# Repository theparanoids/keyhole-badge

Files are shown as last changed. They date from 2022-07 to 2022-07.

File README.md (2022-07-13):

# Paranoids DEFCON Badge
> PCB design and firmware for a badge given out at DEFCON 2022

## Table of Contents

- [Background](#background)
- [Install](#install)
- [Usage](#usage)
- [Contribute](#contribute)
- [License](#license)

## Background

The Paranoids have designed a sound-reactive LED electronic conference badge for DEFCON 2022. This repository contains the PCB design files for the badge and the source code to the firmware that runs on the microcontroller.

This badge is designed around a Nordic [nRF52833](https://www.nordicsemi.com/Products/nRF52833) SoC embedded in a Laird [BL653](https://www.lairdconnect.com/wireless-modules/bluetooth-modules/bluetooth-5-modules/bl653-series-bluetooth-51-802154-nfc-module) module. The badge features wireless connectivity (Bluetooth Low Energy in this firmware implementation), a NFC coil, a microphone, buttons, and LEDs.

The firmware is built using the [nRF Connect SDK](https://www.nordicsemi.com/Products/Development-software/nRF-Connect-SDK) and [Zephyr RTOS](https://zephyrproject.org/). It advertises BLE beacons and listens for beacons coming from neighboring badges, lighting up the LEDs according to the number of badges detected. It also blinks the LEDs either in response to sound or in other patterns, which are unlocked by inputting secret codes using the buttons.

## Install

In order to edit the PCB design files, you will need to install [Kicad](https://www.kicad.org/) version 6 or above. The badge design is located in the `eda/` subdirectory. A pogo pin jig used during manufacturing is located in the `jig/` subdirectory. Opening the `.kicad_pro` project file should automatically load both the schematic and PCB design.

If you only want to view the schematic or the final board layout, PDFs of the final version are located in [final-artefacts](final-artefacts).

In order to compile the firmware, you will need to install the [Nordic nRF Connect SDK](https://www.nordicsemi.com/Products/Development-software/nrf-connect-sdk) v1.9.0. This can be installed according to the official instructions. If you are using nRF Connect for Desktop and the Toolchain Manager, select "Open Terminal" from the arrow dropdown after installing the SDK. From this terminal, the firmware can be built using the following command:

```bash
cd fw/
west build
```

The output will be located in `fw/build/zephyr/zephyr.elf`.

There are miscellaneous scripts written in Python that were used during testing and development. These require Python3, pySerial, NumPy, and scikit-image. These can be installed via pip using the following commands:

```bash
# Create a new Python virtual environment
python3 -m venv venv
# Activate the virtual environment
source venv/bin/activate
# Install libraries
pip install pyserial numpy scikit-image
```

LED positions were computed using [SolveSpace](https://solvespace.com/). This is saved in the [notes.slvs](eda/notes.slvs) file.

## Usage

The Paranoids badge does not contain any kind of bootloader or firmware update functionality, so installing new firmware requires connecting to SWD (Serial Wire Debug) test pads on the back of the badge. This can be done either with a temporary jig or by soldering wires or pin headers. The test points are labeled on the [backside fabrication drawing](final-artefacts/badge/pdf/badge_eda-B_Fab.pdf). Connections that are required are as follows:

* `TP3 / +V` -- Microcontroller supply voltage. This may be labeled as "VCC" or "Vtarget" or similar. Corresponds to pin 1 of the ARM 10-pin connector. **Caution**: This pin is intended to be used as a voltage reference and not as a means to power the badge. Although powering the badge from this test point does work, doing so will bypass the reverse polarity protection circuitry. There is also no protection against back-powering the battery, which can result in a dangerous condition. If power is supplied using this test point, ensure that connections are correct and that batteries are not installed. Nominal voltage 3 V.
* `TP9 / GND` -- Ground reference. Corresponds to pins 3/5/9 of the ARM 10-pin connector.
* `TP5 / SWDCLK` -- SWD clock pin. Corresponds to pin 4 of the ARM 10-pin connector.
* `TP6 / SWDIO` -- SWD data pin. Corresponds to pin 2 of the ARM 10-pin connector.
* `TP4 / ~RST` (optional) -- reset pin (active low). Corresponds to pin 10 of the ARM 10-pin connector. Not required in most cases as reset can be triggered over SWD.
* `TP7 / DBGTX` (optional) -- debug serial port, output from the board. In this firmware, this is configured with a 115200 baud 8n1 serial port for printing debug messages.
* `TP8 / DBGRX` (optional) -- debug serial port, input into the board. In this firmware, this is technically configured as part of the debug console, but input is never read.

All signals are referenced to the voltage on `TP3`.

Programming new firmware requires an external ARM SWD debug probe, such as a [Black Magic Probe](https://1bitsquared.com/products/black-magic-probe) or a [J-Link](https://www.segger.com/products/debug-probes/j-link/). It is also possible to [use a Raspberry Pi](https://learn.adafruit.com/programming-microcontrollers-using-openocd-on-raspberry-pi) or any other compatible debug adapter.

Example commands for programming using a Black Magic Probe:

```
$ arm-none-eabi-gdb build/zephyr/zephyr.elf
(gdb) target extended-remote /dev/cu.usbmodemXXXXXXXX
(gdb) monitor swdp_scan
(gdb) attach 1
(gdb) load
```

### Firmware debugging features

The badge connects the USB pins of the nRF52 chip to a USB micro-B connector on the bottom of the board. In this firmware, this is configured as a CDC-ACM serial port featuring a debug console (different from the one on the test points). Typing `help` will show a list of debug commands.

This USB debug console allows for capturing sound onto a connected computer. To capture sound, send the command `debug sound on`. The badge will then continuously output a stream of audio samples in signed 16-bit little endian format at 16 kHz with no framing. The [test_sound.py](fw/src/test_sound.py) script demonstrates capturing approximately 10 seconds of audio via this mechanism and writing it to a raw file which can be opened in tools such as [Audacity](https://www.audacityteam.org/).

If the flash memory of the nRF52 is blank, the firmware will start in factory test mode. Completion of factory testing is stored in flash memory, so none of the badges given out at DEFCON will start in test mode. As long as the Zephyr NVS data at the end of flash memory is not erased when programming new firmware, the badge will not enter test mode again. Test mode can be either re-entered after completion or forcefully bypassed without completing it by using the USB debug console. The factory test procedure goes through the following phases:

1. Both eyes should be red. The edge LEDs should have a pattern of three lit LEDs animating and moving around in a loop. The other LEDs on the edge should be off. One LED should be blue, the next should be green, and the final lit LED should be red. The primary purpose of this test phase is to ensure that there are no breaks in the LED chain. To proceed to the next phase, press button SW1.
2. Both eyes should be green. One LED on the edge, immediately below the eyes, should be white. All other LEDs on the edge should be off. To proceed to the next phase, press button SW2.
3. Both eyes should be blue. Two LEDs on the edge, immediately below the eyes, should be white. All other LEDs on the edge should be off. To proceed to the next phase, press button SW3.
4. Both eyes should be white. Three LEDs on the edge, immediately below the eyes, should be white. All other LEDs on the edge should be off. To proceed to the next phase, press button SW4.
5. Both eyes should be white. All LEDs on the edge should be white. At this point in the test procedure, the edge LEDs, all three primary colors of the eye LEDs, and all buttons will have been tested. This phase with all LEDs lit also serves as a brief test of maximum current draw in order to try to catch obvious issues with the 5 V SMPS. To proceed to the next phase (finishing and exiting test mode), play a 440 Hz tone. This tests the microphone.

## Contribute

Please refer to [the contributing.md file](Contributing.md) for information about how to get involved.

## Maintainers
- R: rou@yahooinc.com

## License
- This project is licensed under the terms of the [Apache 2.0](LICENSE-Apache-2.0) open source license. Please refer to [LICENSE](LICENSE) for the full terms.

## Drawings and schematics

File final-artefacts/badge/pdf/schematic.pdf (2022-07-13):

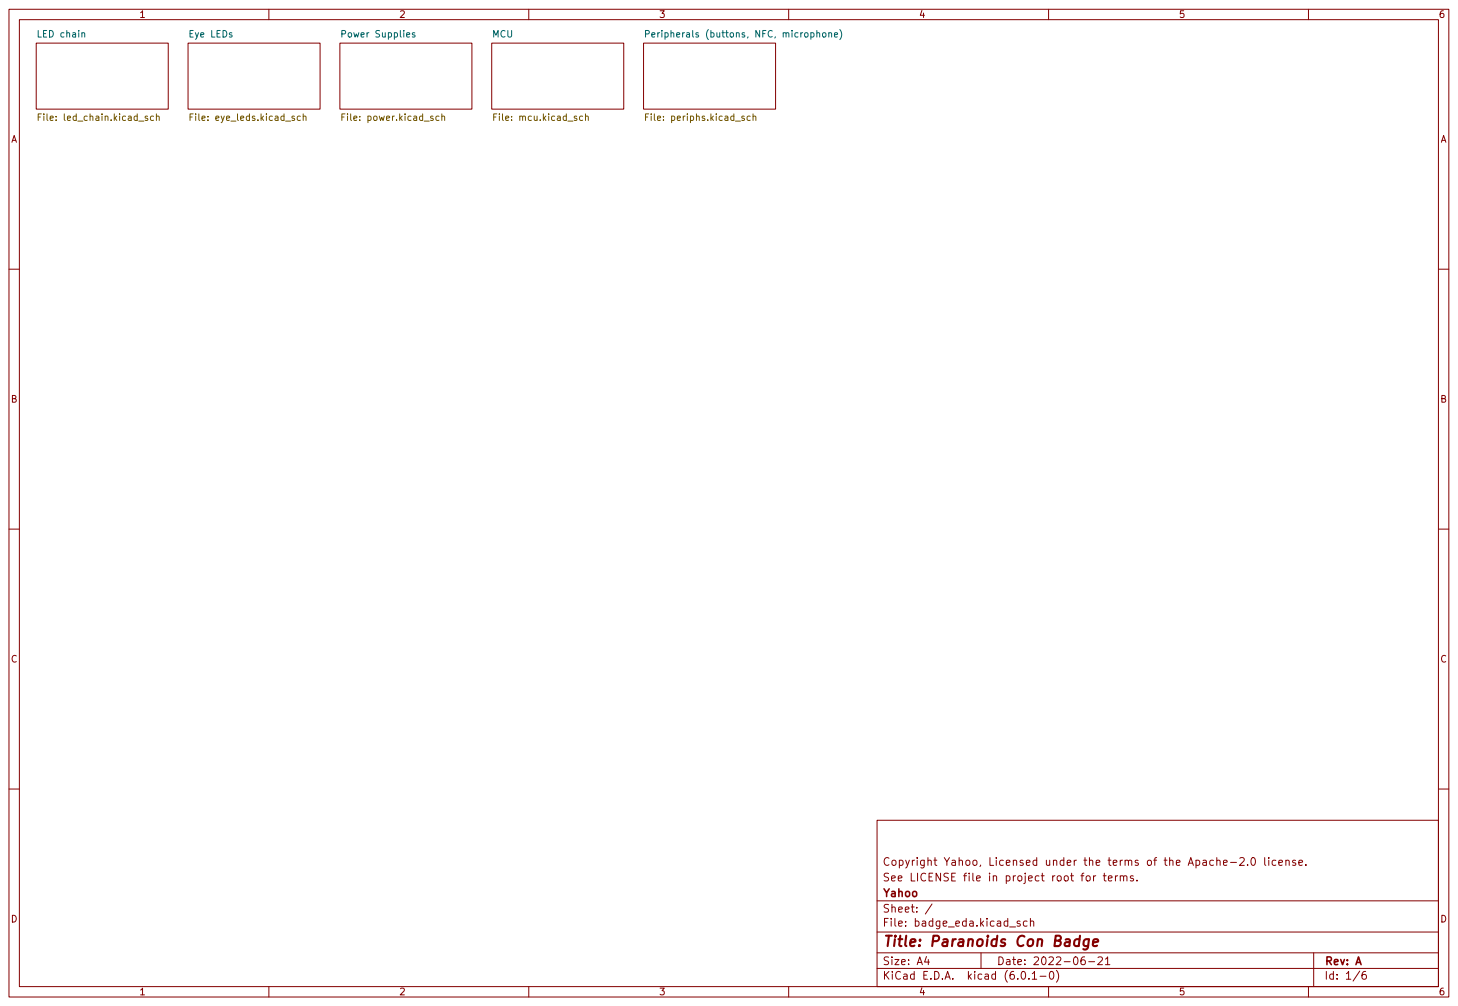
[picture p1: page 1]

Peripherals (buttons, NFC, microphone)

Copyright Yahoo, Licensed under the terms of the Apache-2.0 license.
File: badge_eda.kicad_sch Sheet: / Yahoo See LICENSE file in project root for terms.

Id: 1/6 Title: Paranoids Con Badge

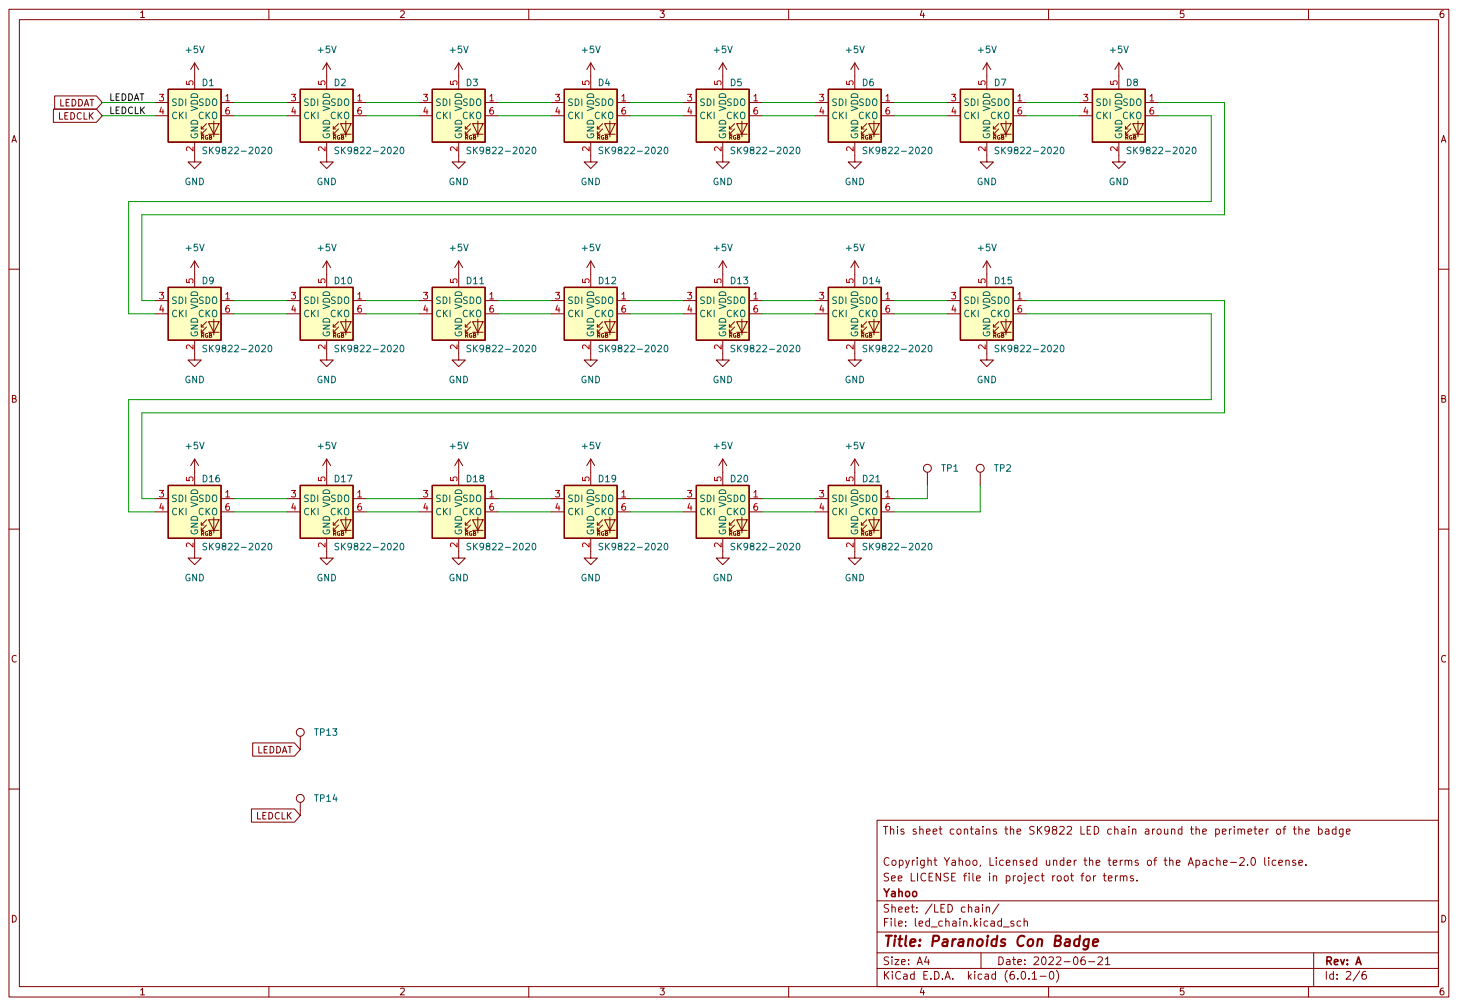
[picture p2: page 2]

This sheet contains the SK9822 LED chain around the perimeter of the badge

Copyright Yahoo, Licensed under the terms of the Apache-2.0 license.
File: led_chain.kicad_sch Sheet: /LED chain/ Yahoo See LICENSE file in project root for terms.

Id: 2/6 Title: Paranoids Con Badge

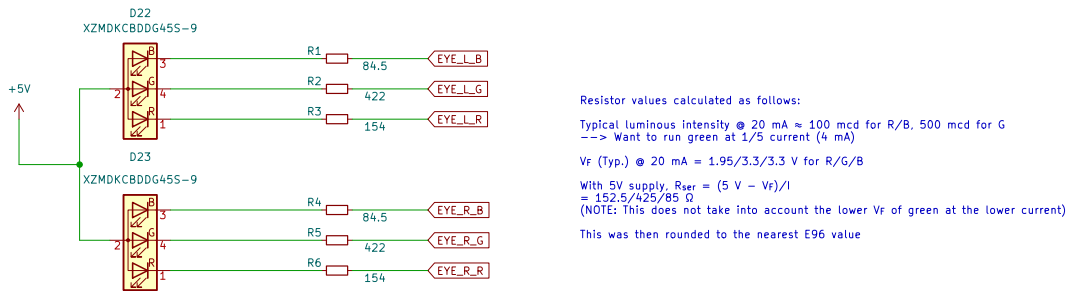
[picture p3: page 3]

Resistor values calculated as follows: þÿTypical luminous intensity @ 20 mA "H 100 mcd for R/B, 500 mcd for G

--> Want to run green at 1/5 current (4 mA)

With 5V supply, R_{ser} = (5 V - V_{F})/I
(NOTE: This does not take into account the lower V_{F} of green at the lower current) This was then rounded to the nearest E96 value

This sheet contains the RGB LEDs that light up behind the eyes

Copyright Yahoo, Licensed under the terms of the Apache-2.0 license.
Sheet: /Eye LEDs/ Yahoo See LICENSE file in project root for terms.

File: eye_leds.kicad_sch
Id: 3/6 Title: Paranoids Con Badge

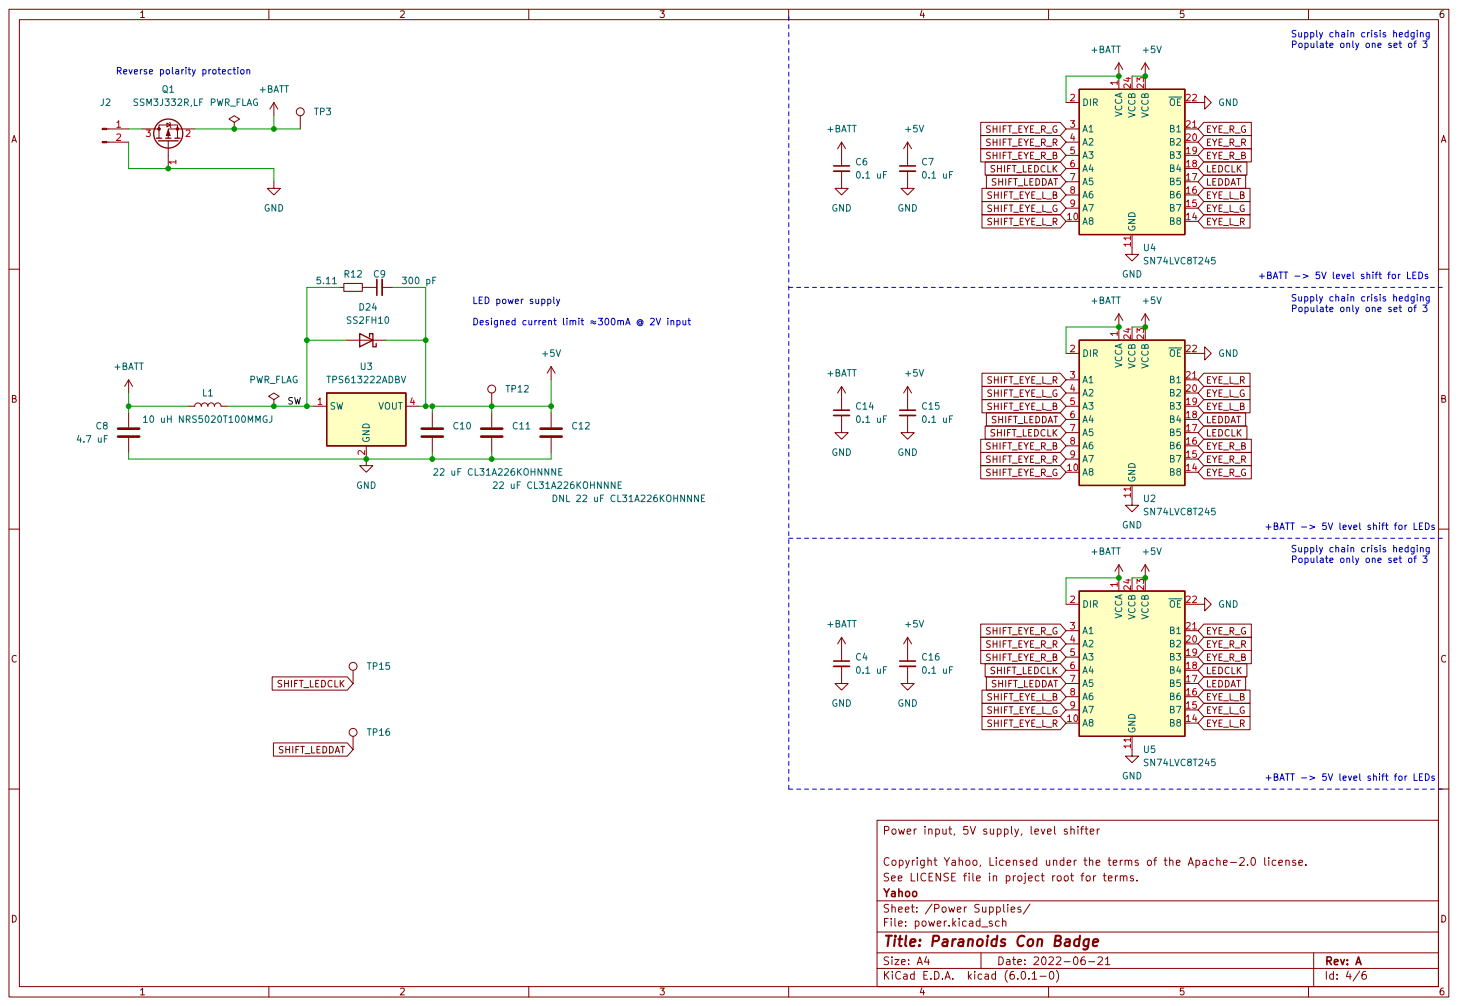
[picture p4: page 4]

Supply chain crisis hedging
Populate only one set of 3
Populate only one set of 3 +BATT -> 5V level shift for LEDs Supply chain crisis hedging

1 A8 10 GND 11 B8 14 B7 15 B6 16 B5 17 B4 18 B3 19 DIR 2 B2 20 B1 21 ~{OE}22 VCCB 23 VCCB 24 A1 3 A2 4 A3 5 A4 6 A5 7 A6 8 A7 9 U4SN74LVC8T245 +5V C12 DNL 22 uF CL31A226KOHNNNE

1 A8 10 GND 11 B8 14 B7 15 B6 16 B5 17 B4 18 B3 19 DIR 2 B2 20 B1 21 ~{OE}22 VCCB 23 VCCB 24 A1 3 A2 4 A3 5 A4 6 A5 7 A6 8 A7 9 U2SN74LVC8T245 GND

+BATT -> 5V level shift for LEDs +BATT -> 5V level shift for LEDs Supply chain crisis hedging

1 A8 10 GND 11 B8 14 B7 15 B6 16 B5 17 B4 18 B3 19 DIR 2 B2 20 B1 21 ~{OE}22 VCCB 23 VCCB 24 A1 3 A2 4 A3 5 A4 6 A5 7 A6 8 A7 9 U5SN74LVC8T245

Power input, 5V supply, level shifter

Copyright Yahoo, Licensed under the terms of the Apache-2.0 license.
Sheet: /Power Supplies/ Yahoo See LICENSE file in project root for terms.

File: power.kicad_sch
Id: 4/6 Title: Paranoids Con Badge

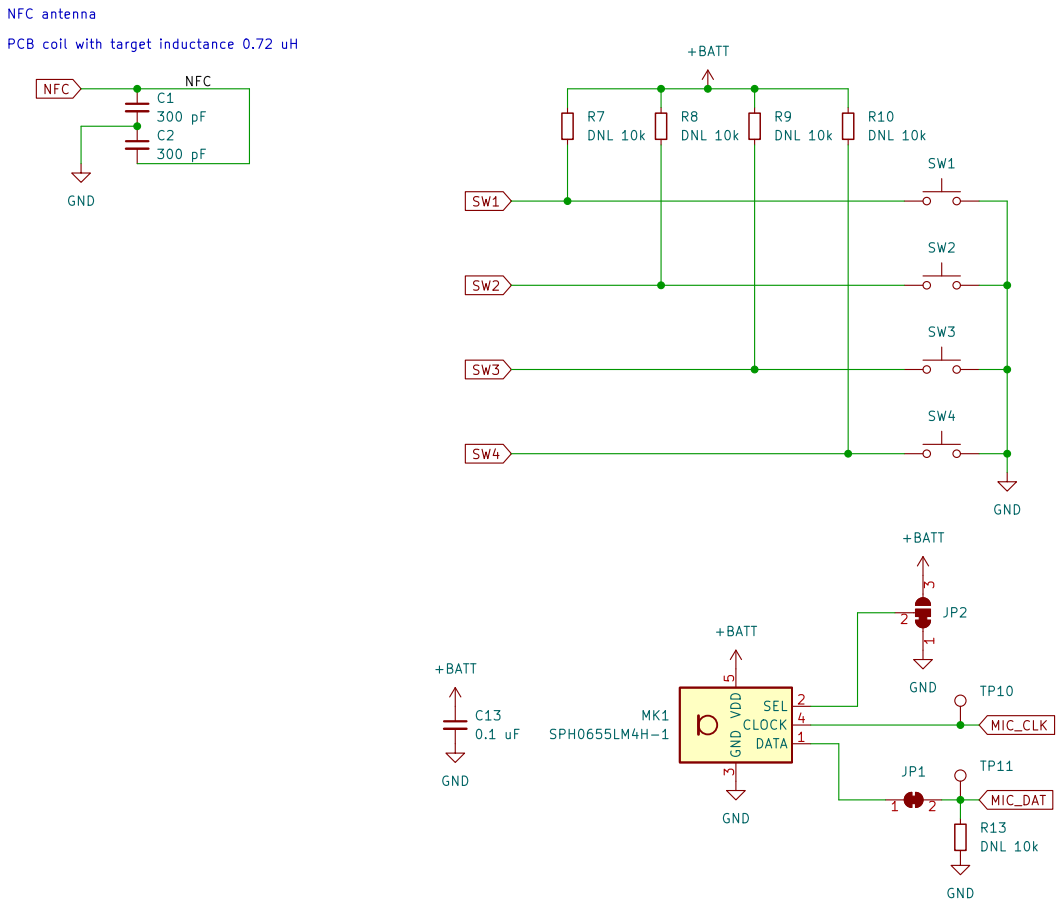
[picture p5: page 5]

NFC antenna PCB coil with target inductance 0.72 uH

Copyright Yahoo, Licensed under the terms of the Apache-2.0 license.
Sheet: /Peripherals (buttons, NFC, microphone)/ Yahoo See LICENSE file in project root for terms.

File: periphs.kicad_sch
Id: 5/6 Title: Paranoids Con Badge

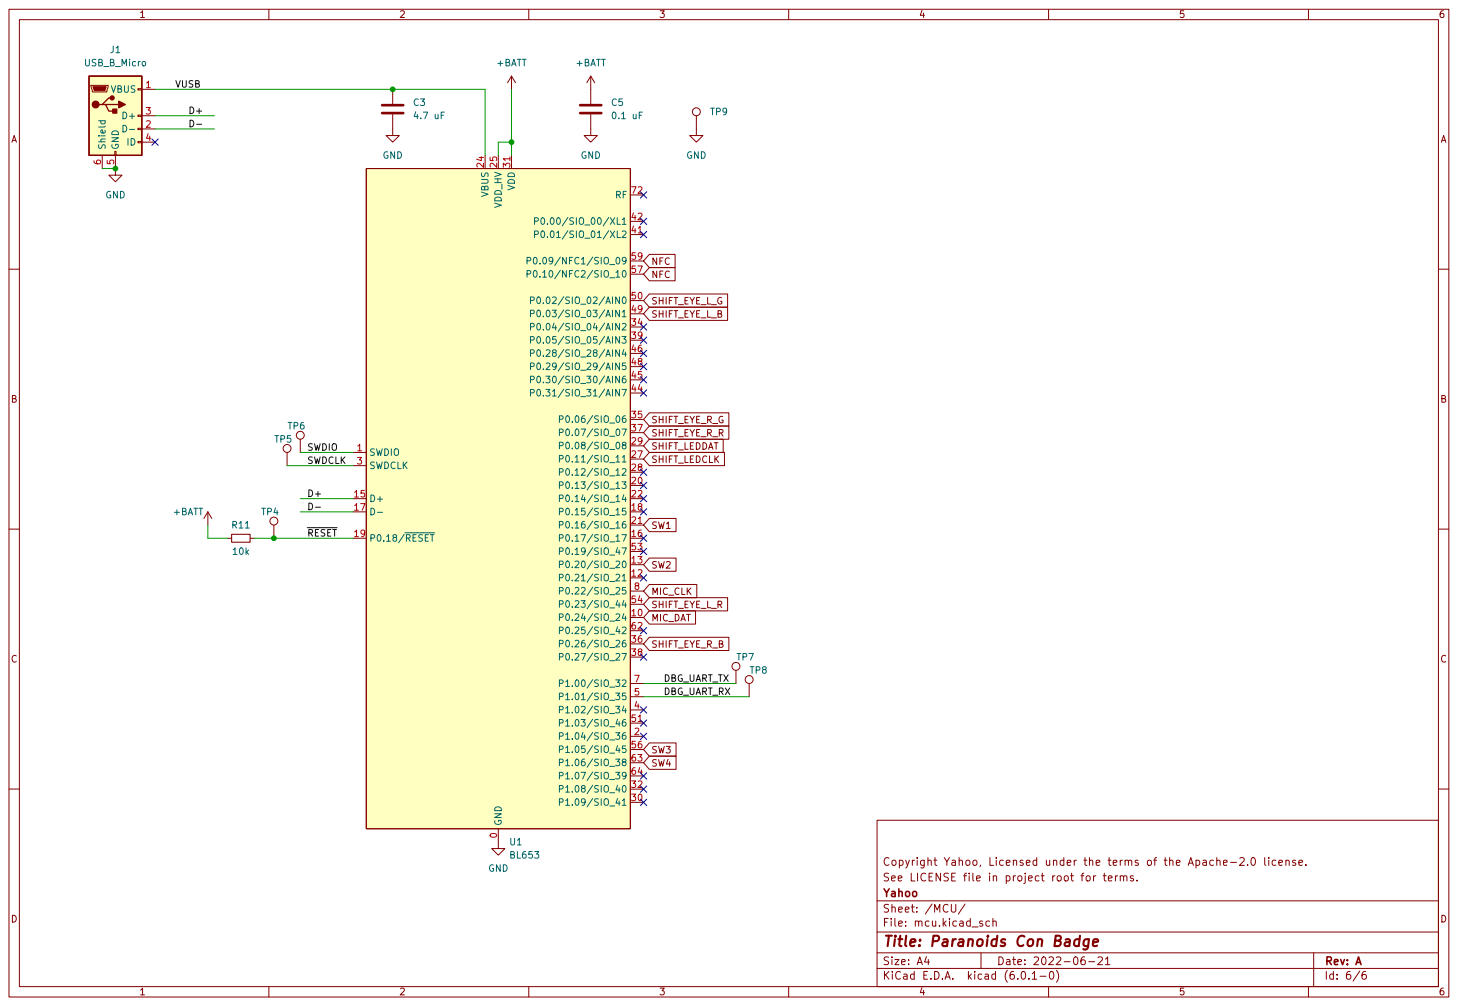
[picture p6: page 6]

Copyright Yahoo, Licensed under the terms of the Apache-2.0 license.
File: mcu.kicad_sch Sheet: /MCU/ Yahoo See LICENSE file in project root for terms.

Id: 6/6 Title: Paranoids Con Badge

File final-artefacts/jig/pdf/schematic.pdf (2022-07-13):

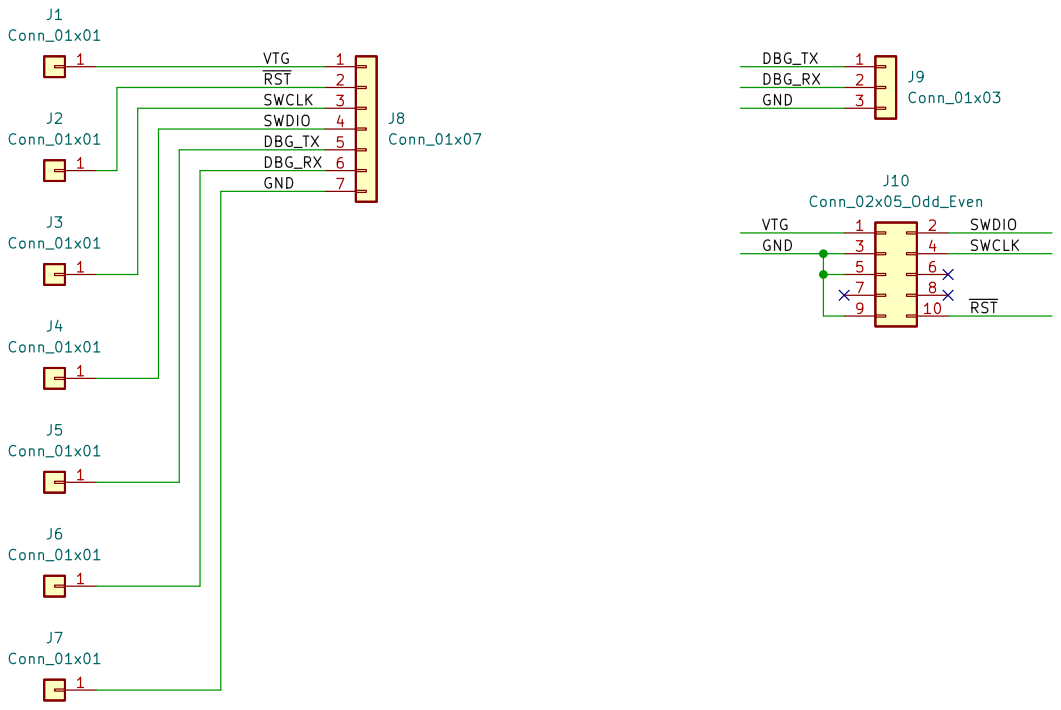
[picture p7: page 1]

Copyright Yahoo, Licensed under the terms of the Apache-2.0 license.
File: badge_jig.kicad_sch Sheet: / Yahoo See LICENSE file in project root for terms.

Id: 1/1 Title: Paranoids Badge Programming Jig

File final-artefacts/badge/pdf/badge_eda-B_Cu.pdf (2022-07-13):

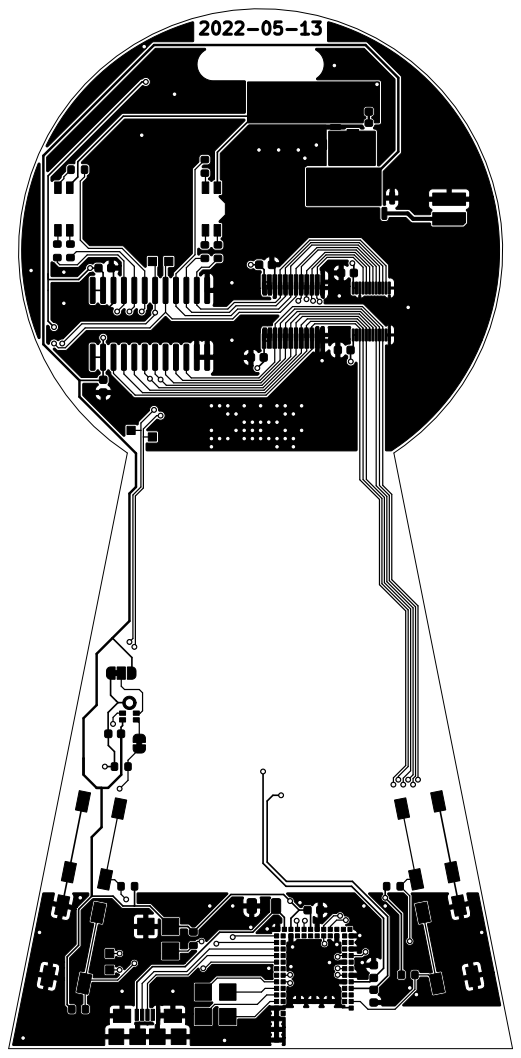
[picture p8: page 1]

Copyright Yahoo, Licensed under the terms of the Apache-2.0 license.
File: badge_eda.kicad_pcb Sheet: Yahoo See LICENSE file in project root for terms.

Id: 1/1 Title: Paranoids Defcon Badge

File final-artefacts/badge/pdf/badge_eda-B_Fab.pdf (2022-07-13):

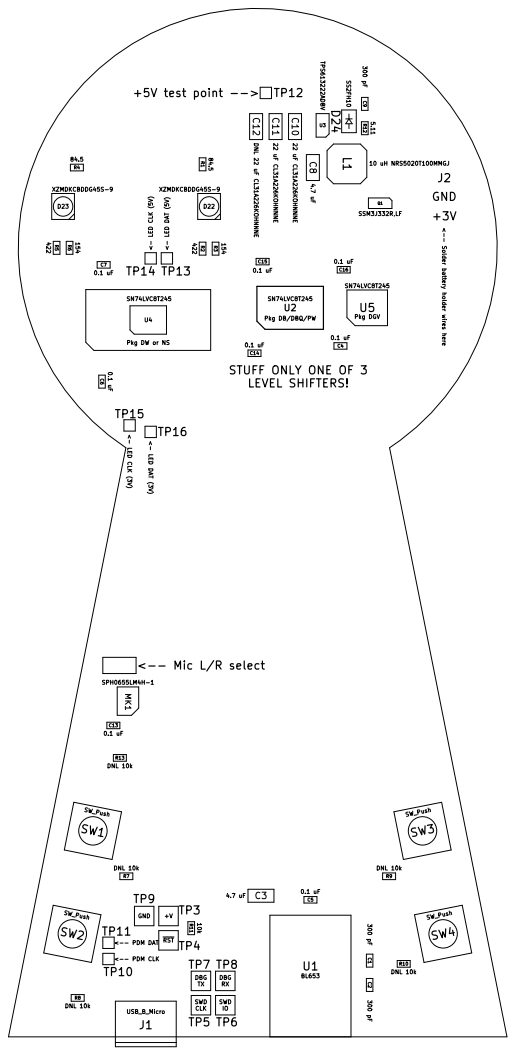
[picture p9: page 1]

DBG | DBG RX

SWD CLK | IO

File: badge_eda.kicad_pcb Sheet: Yahoo See LICENSE file in project root for terms.

Id: 1/1 Title: Paranoids Defcon Badge

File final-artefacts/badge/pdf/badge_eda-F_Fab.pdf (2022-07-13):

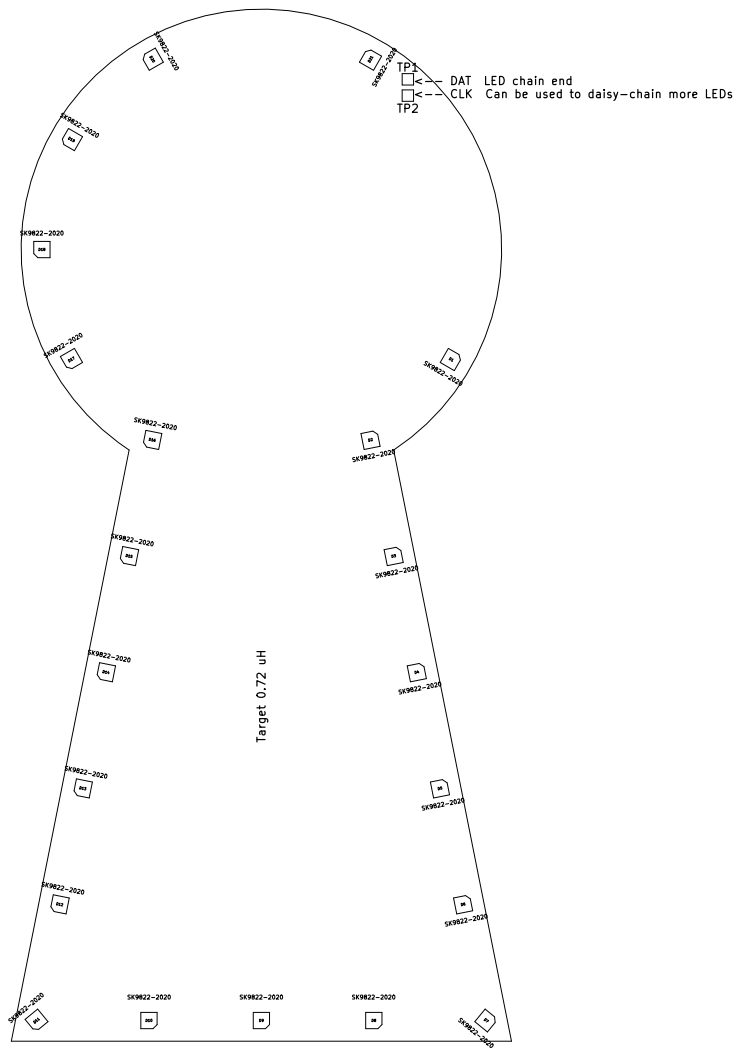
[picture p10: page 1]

<-- DAT LED chain end

<-- CLK Can be used to daisy-chain more LEDs Target 0.72 uH

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

Id: 1/1 Title: Paranoids Defcon Badge

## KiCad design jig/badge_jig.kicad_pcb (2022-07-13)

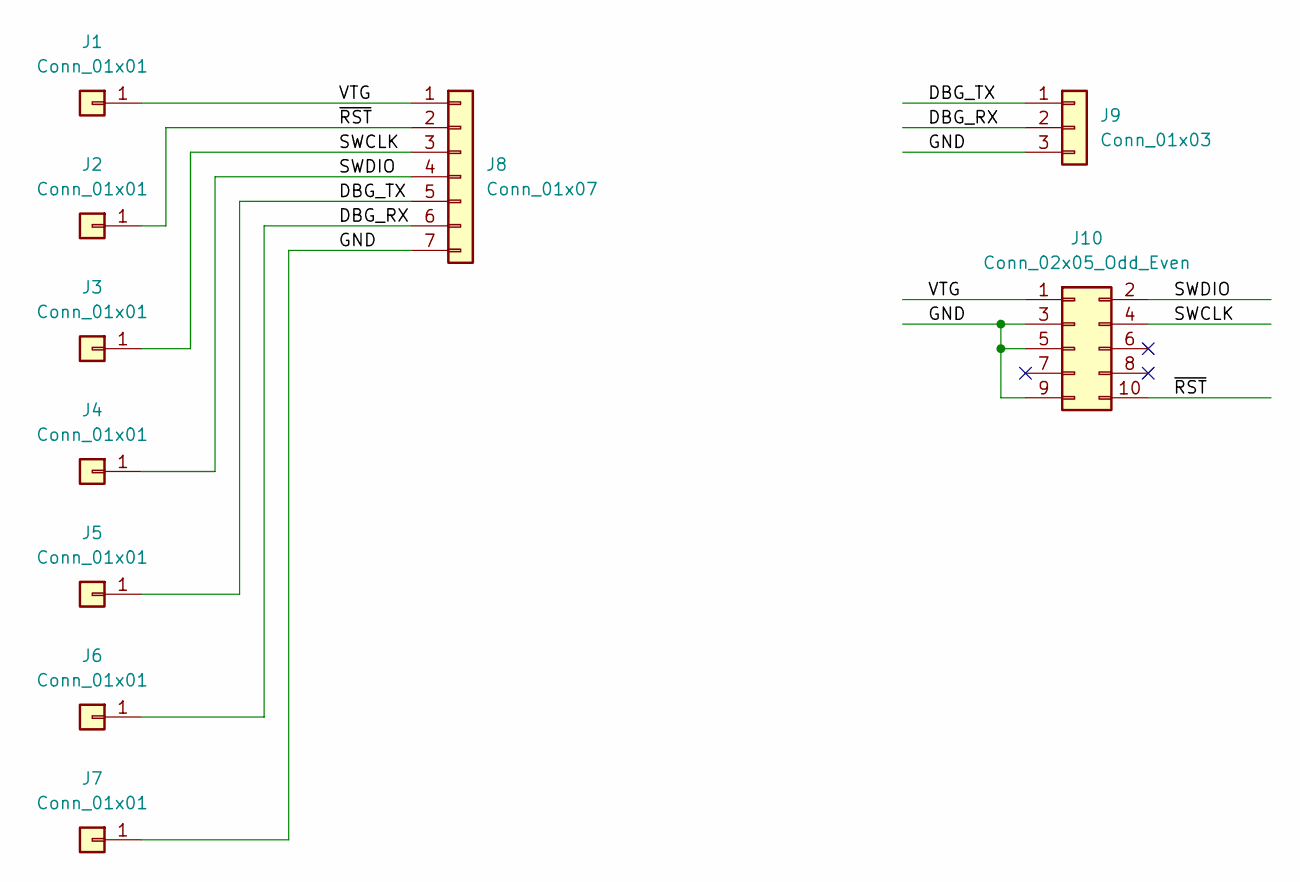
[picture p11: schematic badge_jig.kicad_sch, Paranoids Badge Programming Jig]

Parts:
J1, J2, J3, J4, J5, J6, J7: Conn_01x01; pogopin
J8: Conn_01x07; PinHeader_1x07_P2.54mm_Horizontal
J9: Conn_01x03; PinHeader_1x03_P2.54mm_Horizontal
J10: Conn_02x05_Odd_Even; PinHeader_2x05_P2.54mm_Vertical

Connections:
/DBG_RX: J6.1, J8.6, J9.2
/DBG_TX: J5.1, J8.5, J9.1
/GND: J7.1, J8.7, J9.3, J10.3, J10.5, J10.9
/SWCLK: J3.1, J8.3, J10.4
/SWDIO: J4.1, J8.4, J10.2
/VTG: J1.1, J8.1, J10.1
/~RST: J2.1, J8.2, J10.10

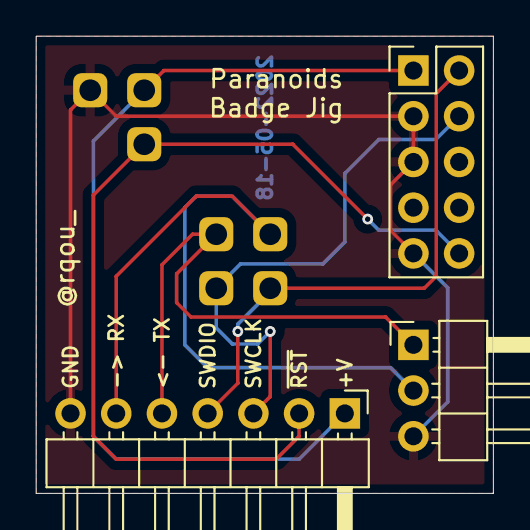
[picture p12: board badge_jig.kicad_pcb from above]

Board: 2 copper layers, 25.4 x 25.4 mm, 10 parts (0 on the bottom side), 7 nets.

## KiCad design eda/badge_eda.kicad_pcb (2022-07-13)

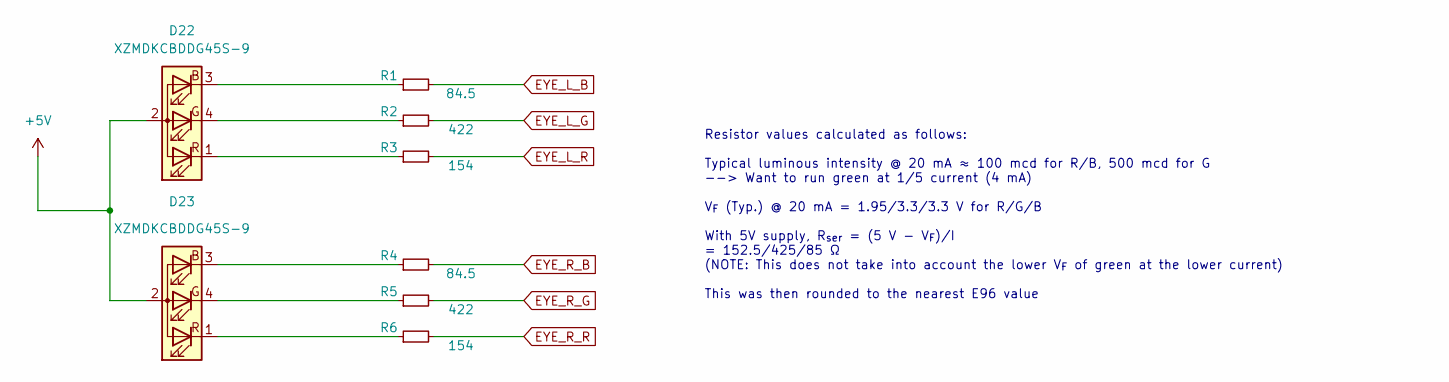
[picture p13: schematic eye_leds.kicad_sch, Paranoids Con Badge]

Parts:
D22, D23: XZMDKCBDDG45S-9; LED_SunLed-PLCC4_3.2x2.8mm_CW
R1, R4: 84.5; R_0603_1608Metric
R2, R5: 422; R_0603_1608Metric
R3, R6: 154; R_0603_1608Metric

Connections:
+5V: D22.2 (A), D23.2 (A); also elsewhere on the board
EYE_L_B: R1.2; also elsewhere on the board
EYE_L_G: R2.2; also elsewhere on the board
EYE_L_R: R3.2; also elsewhere on the board
EYE_R_B: R4.2; also elsewhere on the board
EYE_R_G: R5.2; also elsewhere on the board
EYE_R_R: R6.2; also elsewhere on the board
unnamed: D22.1 (RK), R3.1
unnamed: D22.3 (BK), R1.1
unnamed: D22.4 (GK), R2.1
unnamed: D23.1 (RK), R6.1
unnamed: D23.3 (BK), R4.1
unnamed: D23.4 (GK), R5.1

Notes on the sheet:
Resistor values calculated as follows: Typical luminous intensity @ 20 mA ≈ 100 mcd for R/B, 500 mcd for G --> Want to run green at 1/5 current (4 mA) V_{F} (Typ.) @ 20 mA = 1.95/3.3/3.3 V for R/G/B With 5V supply, R_{ser} = (5 V - V_{F})/I = 152.5/425/85 Ω (NOTE: This does not take into account th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

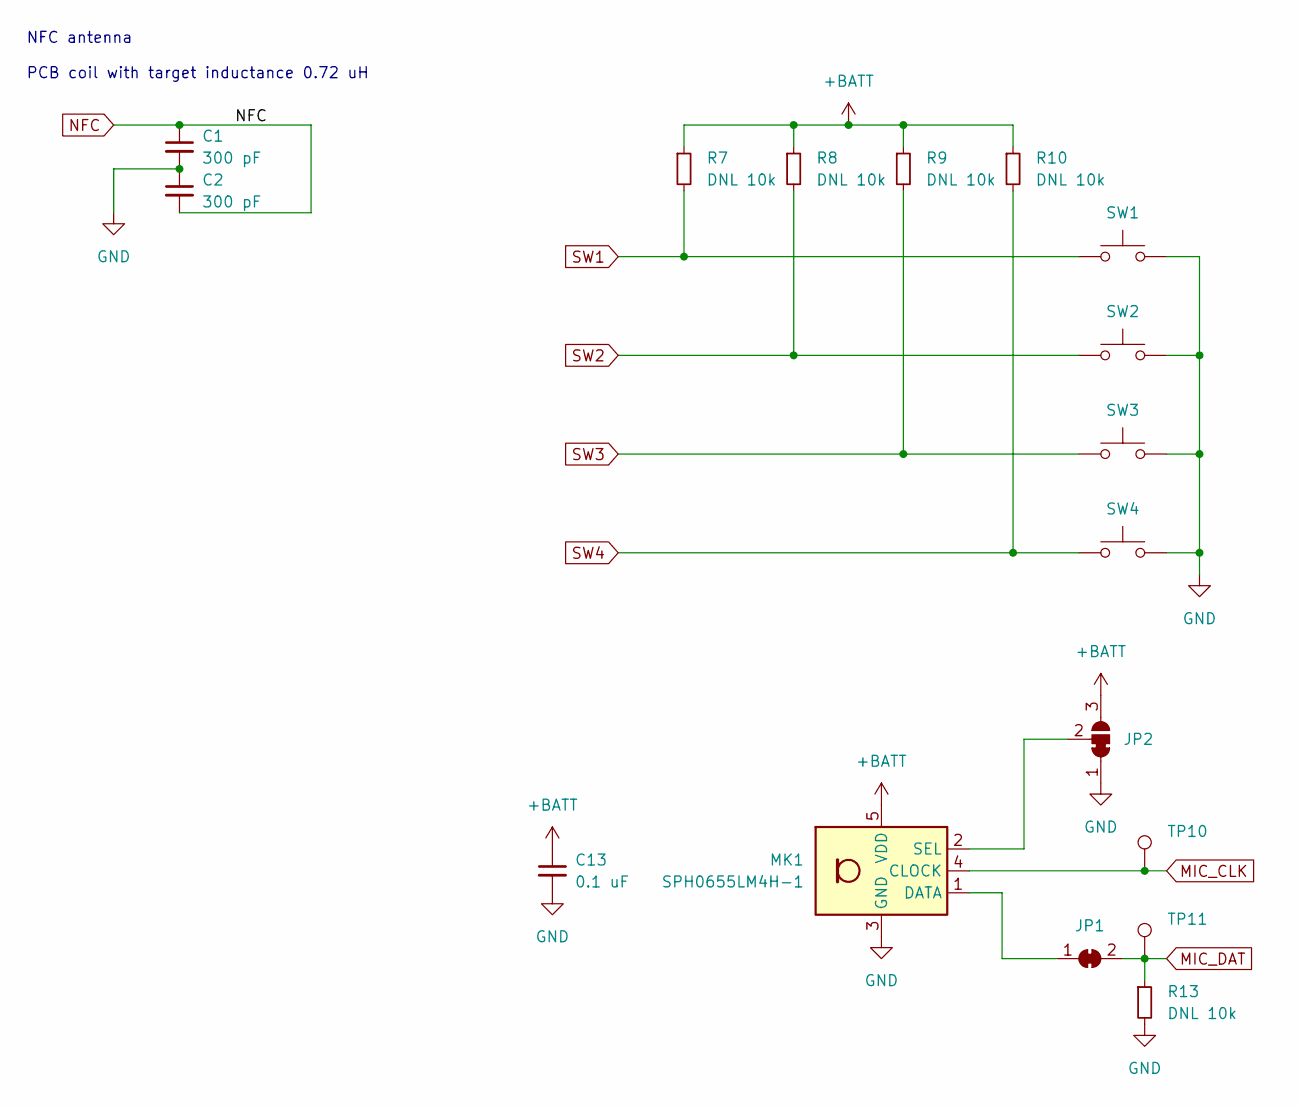
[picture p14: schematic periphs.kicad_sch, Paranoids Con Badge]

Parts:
C1, C2: 300 pF; C_0603_1608Metric
C13: 0.1 uF; C_0603_1608Metric
JP1: SolderJumper_2_Bridged; SolderJumper-2_P1.3mm_Bridged_RoundedPad1.0x1.5mm
JP2: SolderJumper_3_Bridged12; SolderJumper-3_P1.3mm_Bridged12_RoundedPad1.0x1.5mm
MK1: SPH0655LM4H-1; Knowles_LGA-5_3.5x2.65mm
R7, R8, R9, R10, R13: DNL 10k; R_0603_1608Metric
SW1, SW2, SW3, SW4: SW_Push; FIXED_SW_Push_1P1T_NO_6x6mm_H9.5mm
TP10, TP11: TestPoint; TestPoint_Pad_1.0x1.0mm

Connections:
+BATT: C13.1, JP2.3 (B), MK1.5 (VDD), R7.1, R8.1, R9.1, R10.1; also elsewhere on the board
GND: C1.2, C2.1, C13.2, JP2.1 (A), MK1.3 (GND), R13.2, SW1.2, SW2.2, SW3.2, SW4.2; also elsewhere on the board
MIC_CLK: MK1.4 (CLOCK), TP10.1; also elsewhere on the board
MIC_DAT: JP1.2 (B), R13.1, TP11.1; also elsewhere on the board
NFC: C1.1, C2.2; also elsewhere on the board
unnamed: JP1.1 (A), MK1.1 (DATA)
unnamed: JP2.2 (C), MK1.2 (SEL)
SW1: R7.2, SW1.1; also elsewhere on the board
SW2: R8.2, SW2.1; also elsewhere on the board
SW3: R9.2, SW3.1; also elsewhere on the board
SW4: R10.2, SW4.1; also elsewhere on the board

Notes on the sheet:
NFC antenna PCB coil with target inductance 0.72 uH

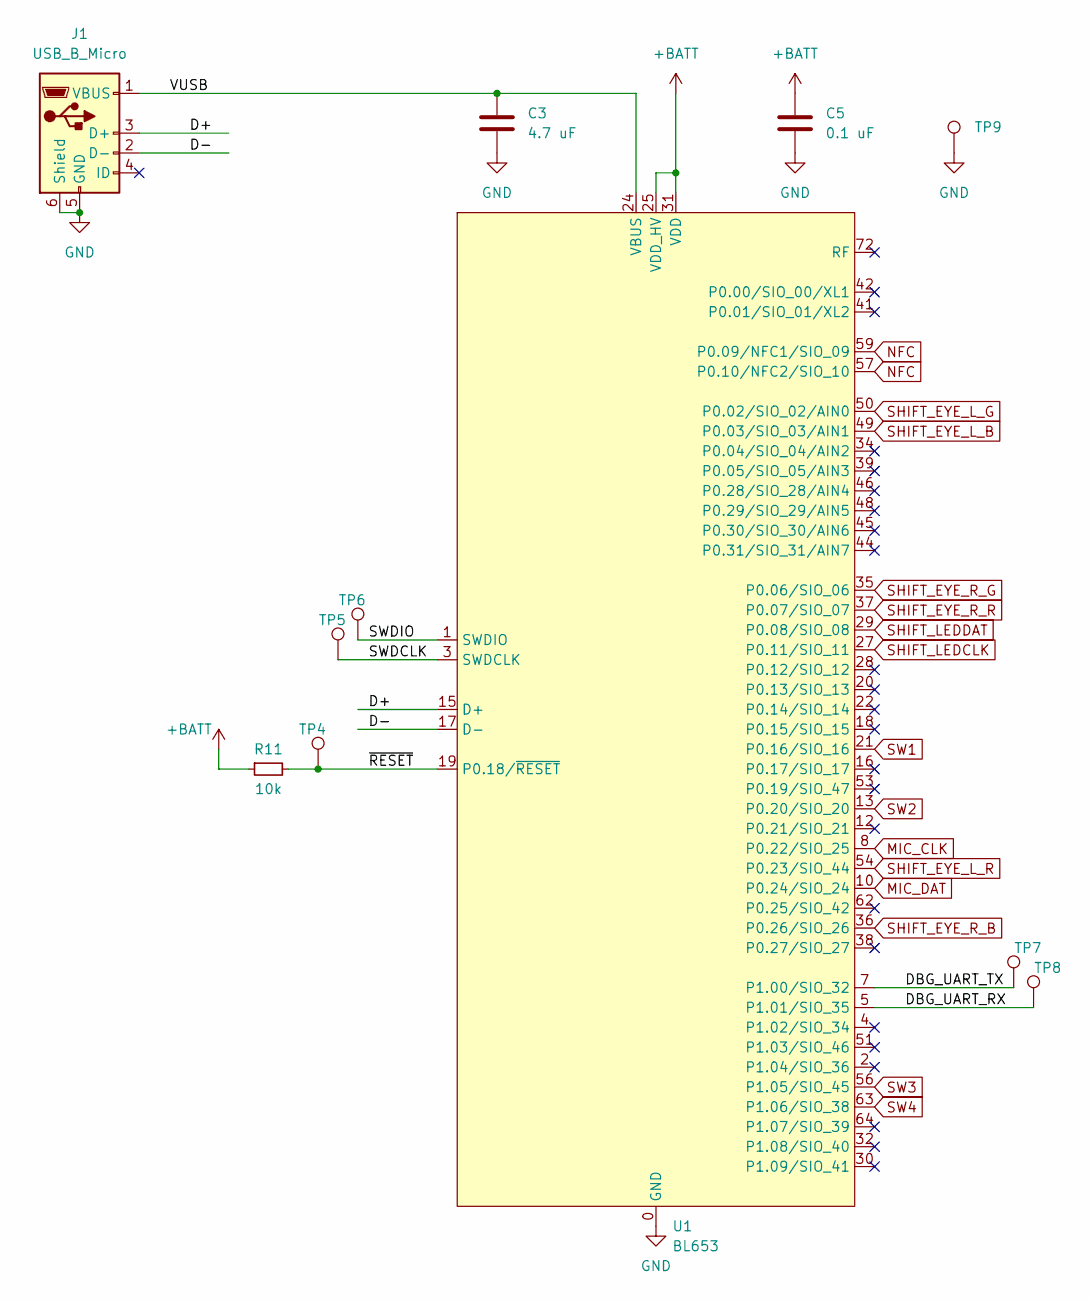
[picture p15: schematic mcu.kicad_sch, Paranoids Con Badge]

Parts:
C3: 4.7 uF; C_1206_3216Metric
C5: 0.1 uF; C_0603_1608Metric
J1: USB_B_Micro; USB_Micro-B_Amphenol_10118192-0001LF_Horizontal
R11: 10k; R_0603_1608Metric
TP4, TP5, TP6, TP7, TP8, TP9: TestPoint; TestPoint_Pad_2.0x2.0mm
U1: BL653

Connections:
+BATT: C5.1, R11.1, U1.25 (VDD_HV), U1.31 (VDD); also elsewhere on the board
/MCU/D+: J1.3 (D+), U1.15 (D+)
/MCU/D-: J1.2 (D-), U1.17 (D-)
/MCU/DBG_UART_RX: TP8.1, U1.5 (P1.01/SIO_35)
/MCU/DBG_UART_TX: TP7.1, U1.7 (P1.00/SIO_32)
/MCU/SWDCLK: TP5.1, U1.3 (SWDCLK)
/MCU/SWDIO: TP6.1, U1.1 (SWDIO)
/MCU/VUSB: C3.1, J1.1 (VBUS), U1.24 (VBUS)
/MCU/~RESET: R11.2, TP4.1, U1.19 (P0.18/~RESET)
GND: C3.2, C5.2, J1.5 (GND), J1.6 (Shield), TP9.1, U1.0 (GND), U1.23 (GND), U1.26 (GND), U1.33 (GND), U1.40 (GND), U1.43 (GND), U1.47 (GND), U1.52 (GND), U1.55 (GND), U1.58 (GND), U1.65 (GND), U1.66 (GND), U1.67 (GND), U1.68 (GND), U1.69 (GND), U1.70 (GND), U1.71 (GND); also elsewhere on the board
MIC_CLK: U1.8 (P0.22/SIO_25); also elsewhere on the board
MIC_DAT: U1.10 (P0.24/SIO_24); also elsewhere on the board
NFC: U1.57 (P0.10/NFC2/SIO_10), U1.59 (P0.09/NFC1/SIO_09); also elsewhere on the board
SHIFT_EYE_L_B: U1.49 (P0.03/SIO_03/AIN1); also elsewhere on the board
SHIFT_EYE_L_G: U1.50 (P0.02/SIO_02/AIN0); also elsewhere on the board
SHIFT_EYE_L_R: U1.54 (P0.23/SIO_44); also elsewhere on the board
SHIFT_EYE_R_B: U1.36 (P0.26/SIO_26); also elsewhere on the board
SHIFT_EYE_R_G: U1.35 (P0.06/SIO_06); also elsewhere on the board
SHIFT_EYE_R_R: U1.37 (P0.07/SIO_07); also elsewhere on the board
SHIFT_LEDCLK: U1.27 (P0.11/SIO_11); also elsewhere on the board
SHIFT_LEDDAT: U1.29 (P0.08/SIO_08); also elsewhere on the board
SW1: U1.21 (P0.16/SIO_16); also elsewhere on the board
SW2: U1.13 (P0.20/SIO_20); also elsewhere on the board
SW3: U1.56 (P1.05/SIO_45); also elsewhere on the board
SW4: U1.63 (P1.06/SIO_38); also elsewhere on the board

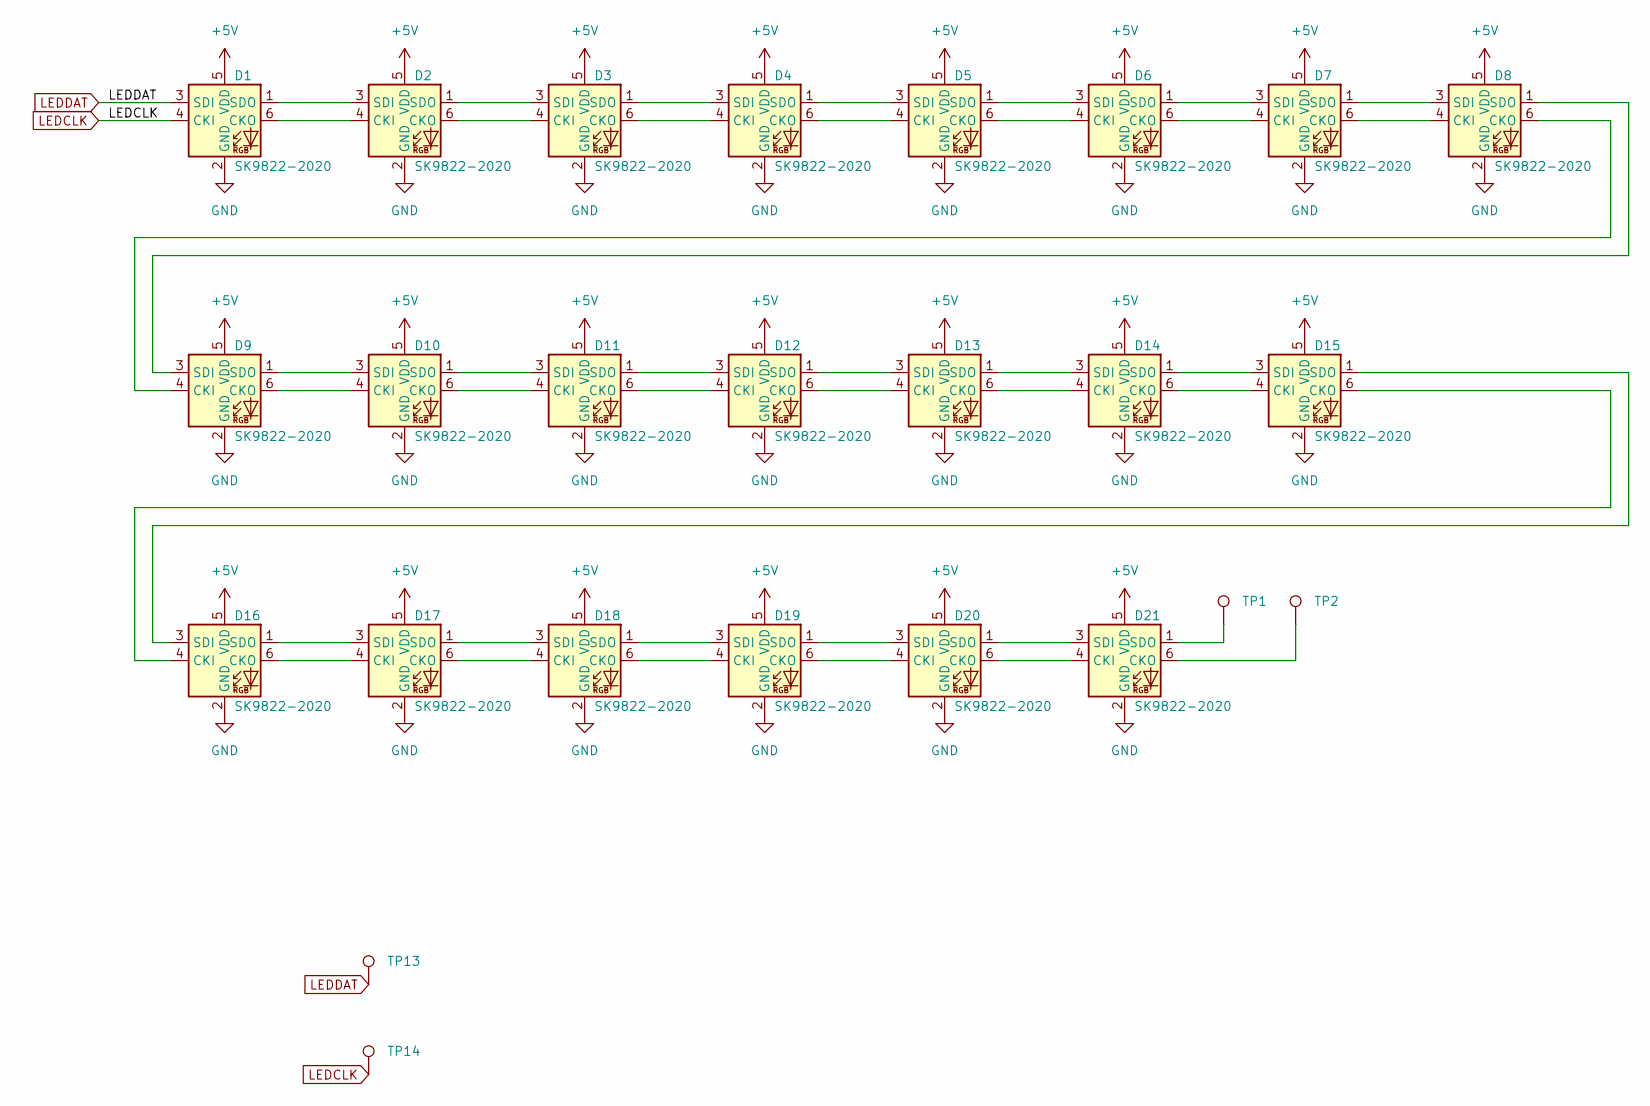
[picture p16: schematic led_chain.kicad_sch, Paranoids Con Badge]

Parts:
D1, D2, D3, D4, D5, D6, D7, D8, D9, D10, D11, D12, D13, D14, D15, D16, D17, D18, D19, D20, D21: SK9822-2020; LED-SK9822-2020
TP1, TP2, TP13, TP14: TestPoint; TestPoint_Pad_1.0x1.0mm

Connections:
+5V: D1.5 (VDD), D2.5 (VDD), D3.5 (VDD), D4.5 (VDD), D5.5 (VDD), D6.5 (VDD), D7.5 (VDD), D8.5 (VDD), D9.5 (VDD), D10.5 (VDD), D11.5 (VDD), D12.5 (VDD), D13.5 (VDD), D14.5 (VDD), D15.5 (VDD), D16.5 (VDD), D17.5 (VDD), D18.5 (VDD), D19.5 (VDD), D20.5 (VDD), D21.5 (VDD); also elsewhere on the board
GND: D1.2 (GND), D2.2 (GND), D3.2 (GND), D4.2 (GND), D5.2 (GND), D6.2 (GND), D7.2 (GND), D8.2 (GND), D9.2 (GND), D10.2 (GND), D11.2 (GND), D12.2 (GND), D13.2 (GND), D14.2 (GND), D15.2 (GND), D16.2 (GND), D17.2 (GND), D18.2 (GND), D19.2 (GND), D20.2 (GND), D21.2 (GND); also elsewhere on the board
LEDCLK: D1.4 (CKI), TP14.1; also elsewhere on the board
LEDDAT: D1.3 (SDI), TP13.1; also elsewhere on the board
unnamed: D1.1 (SDO), D2.3 (SDI)
unnamed: D1.6 (CKO), D2.4 (CKI)
unnamed: D2.1 (SDO), D3.3 (SDI)
unnamed: D2.6 (CKO), D3.4 (CKI)
unnamed: D3.1 (SDO), D4.3 (SDI)
unnamed: D3.6 (CKO), D4.4 (CKI)
unnamed: D4.1 (SDO), D5.3 (SDI)
unnamed: D4.6 (CKO), D5.4 (CKI)
unnamed: D5.1 (SDO), D6.3 (SDI)
unnamed: D5.6 (CKO), D6.4 (CKI)
unnamed: D6.1 (SDO), D7.3 (SDI)
unnamed: D6.6 (CKO), D7.4 (CKI)
unnamed: D7.1 (SDO), D8.3 (SDI)
unnamed: D7.6 (CKO), D8.4 (CKI)
unnamed: D8.1 (SDO), D9.3 (SDI)
unnamed: D8.6 (CKO), D9.4 (CKI)
unnamed: D10.1 (SDO), D11.3 (SDI)
unnamed: D9.1 (SDO), D10.3 (SDI)
unnamed: D9.6 (CKO), D10.4 (CKI)
unnamed: D10.6 (CKO), D11.4 (CKI)
unnamed: D11.1 (SDO), D12.3 (SDI)
unnamed: D11.6 (CKO), D12.4 (CKI)
unnamed: D12.1 (SDO), D13.3 (SDI)
unnamed: D12.6 (CKO), D13.4 (CKI)
unnamed: D13.1 (SDO), D14.3 (SDI)
unnamed: D13.6 (CKO), D14.4 (CKI)
unnamed: D14.1 (SDO), D15.3 (SDI)
unnamed: D14.6 (CKO), D15.4 (CKI)
unnamed: D15.1 (SDO), D16.3 (SDI)
unnamed: D15.6 (CKO), D16.4 (CKI)
unnamed: D16.1 (SDO), D17.3 (SDI)
unnamed: D16.6 (CKO), D17.4 (CKI)
unnamed: D17.1 (SDO), D18.3 (SDI)
unnamed: D17.6 (CKO), D18.4 (CKI)
unnamed: D18.1 (SDO), D19.3 (SDI)
unnamed: D18.6 (CKO), D19.4 (CKI)
unnamed: D19.1 (SDO), D20.3 (SDI)
unnamed: D19.6 (CKO), D20.4 (CKI)
unnamed: D20.1 (SDO), D21.3 (SDI)
unnamed: D20.6 (CKO), D21.4 (CKI)
unnamed: D21.1 (SDO), TP1.1
unnamed: D21.6 (CKO), TP2.1

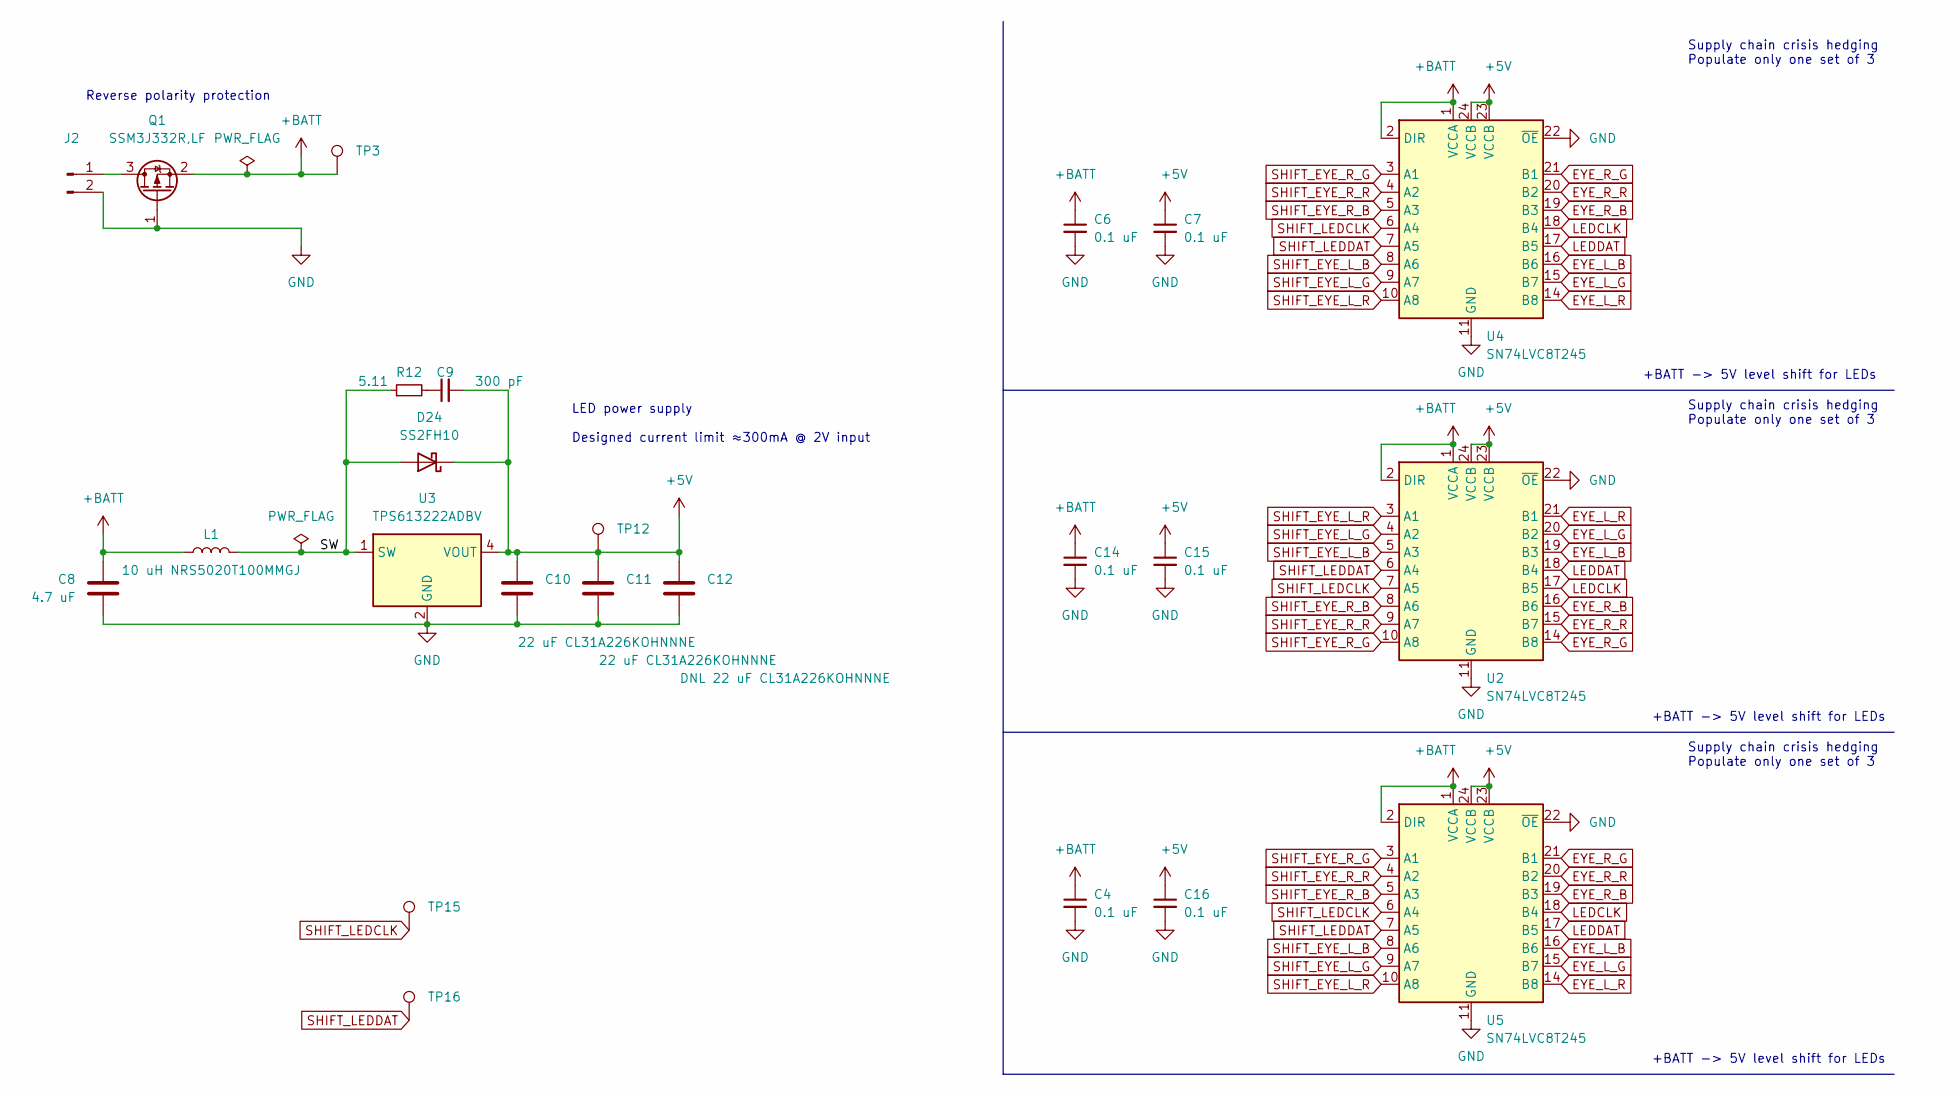
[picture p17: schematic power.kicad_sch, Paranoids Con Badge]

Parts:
C4, C6, C7, C14, C15, C16: 0.1 uF; C_0603_1608Metric
C8: 4.7 uF; C_1206_3216Metric
C9: 300 pF; C_0603_1608Metric
C10, C11: 22 uF CL31A226KOHNNNE; C_1206_3216Metric
C12: DNL 22 uF CL31A226KOHNNNE; C_1206_3216Metric
D24: SS2FH10; D_SMF
J2: Conn_01x02_Male; BATTERY_PADS
L1: 10 uH NRS5020T100MMGJ; L_Taiyo-Yuden_NR-50xx
Q1: SSM3J332R,LF; SOT-23
R12: 5.11; R_0603_1608Metric
TP3: TestPoint; TestPoint_Pad_2.0x2.0mm
TP12, TP15, TP16: TestPoint; TestPoint_Pad_1.0x1.0mm
U2: SN74LVC8T245; SupplyChainFML-DB_DBQ_PW-24
U3: TPS613222ADBV; SOT-23-5
U4: SN74LVC8T245; SupplyChainFML-SO_SOIC-24
U5: SN74LVC8T245; TSSOP-24_4.4x5mm_P0.4mm

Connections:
+5V: C7.1, C9.2, C10.1, C11.1, C12.1, C15.1, C16.1, D24.1 (K), TP12.1, U2.23 (VCCB), U2.24 (VCCB), U3.3 (NC), U3.4 (VOUT), U4.23 (VCCB), U4.24 (VCCB), U5.23 (VCCB), U5.24 (VCCB); also elsewhere on the board
+BATT: C4.1, C6.1, C8.2, C14.1, L1.1, Q1.2 (S), TP3.1, U2.1 (VCCA), U2.2 (DIR), U4.1 (VCCA), U4.2 (DIR), U5.1 (VCCA), U5.2 (DIR); also elsewhere on the board
/Power Supplies/SW: D24.2 (A), L1.2, R12.1, U3.1 (SW)
EYE_L_B: U2.19 (B3), U4.16 (B6), U5.16 (B6); also elsewhere on the board
EYE_L_G: U2.20 (B2), U4.15 (B7), U5.15 (B7); also elsewhere on the board
EYE_L_R: U2.21 (B1), U4.14 (B8), U5.14 (B8); also elsewhere on the board
EYE_R_B: U2.16 (B6), U4.19 (B3), U5.19 (B3); also elsewhere on the board
EYE_R_G: U2.14 (B8), U4.21 (B1), U5.21 (B1); also elsewhere on the board
EYE_R_R: U2.15 (B7), U4.20 (B2), U5.20 (B2); also elsewhere on the board
GND: C4.2, C6.2, C7.2, C8.1, C10.2, C11.2, C12.2, C14.2, C15.2, C16.2, J2.2, Q1.1 (G), U2.11 (GND), U2.12 (GND), U2.13 (GND), U2.22 (~OE), U3.2 (GND), U3.5 (NC), U4.11 (GND), U4.12 (GND), U4.13 (GND), U4.22 (~OE), U5.11 (GND), U5.12 (GND), U5.13 (GND), U5.22 (~OE); also elsewhere on the board
LEDCLK: U2.17 (B5), U4.18 (B4), U5.18 (B4); also elsewhere on the board
LEDDAT: U2.18 (B4), U4.17 (B5), U5.17 (B5); also elsewhere on the board
unnamed: C9.1, R12.2
unnamed: J2.1, Q1.3 (D)
SHIFT_EYE_L_B: U2.5 (A3), U4.8 (A6), U5.8 (A6); also elsewhere on the board
SHIFT_EYE_L_G: U2.4 (A2), U4.9 (A7), U5.9 (A7); also elsewhere on the board
SHIFT_EYE_L_R: U2.3 (A1), U4.10 (A8), U5.10 (A8); also elsewhere on the board
SHIFT_EYE_R_B: U2.8 (A6), U4.5 (A3), U5.5 (A3); also elsewhere on the board
SHIFT_EYE_R_G: U2.10 (A8), U4.3 (A1), U5.3 (A1); also elsewhere on the board
SHIFT_EYE_R_R: U2.9 (A7), U4.4 (A2), U5.4 (A2); also elsewhere on the board
SHIFT_LEDCLK: TP15.1, U2.7 (A5), U4.6 (A4), U5.6 (A4); also elsewhere on the board
SHIFT_LEDDAT: TP16.1, U2.6 (A4), U4.7 (A5), U5.7 (A5); also elsewhere on the board

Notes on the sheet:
+BATT -> 5V level shift for LEDs
Reverse polarity protection
LED power supply Designed current limit ≈300mA @ 2V input
Supply chain crisis hedging Populate only one set of 3

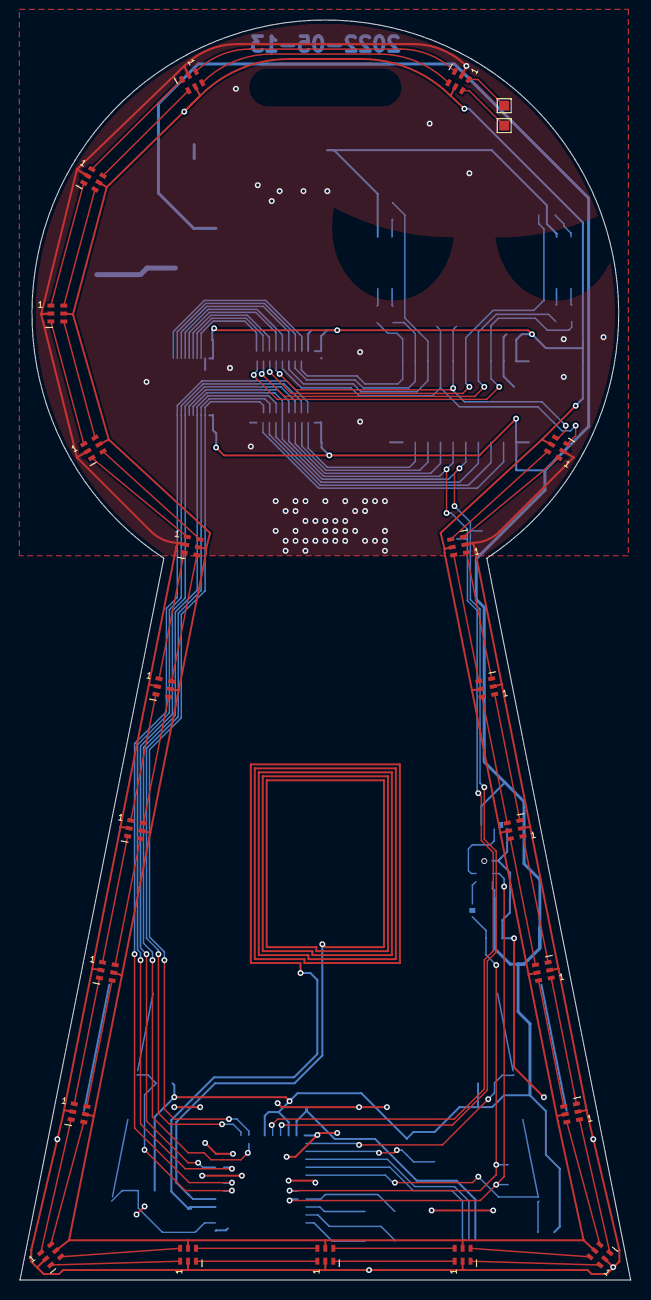
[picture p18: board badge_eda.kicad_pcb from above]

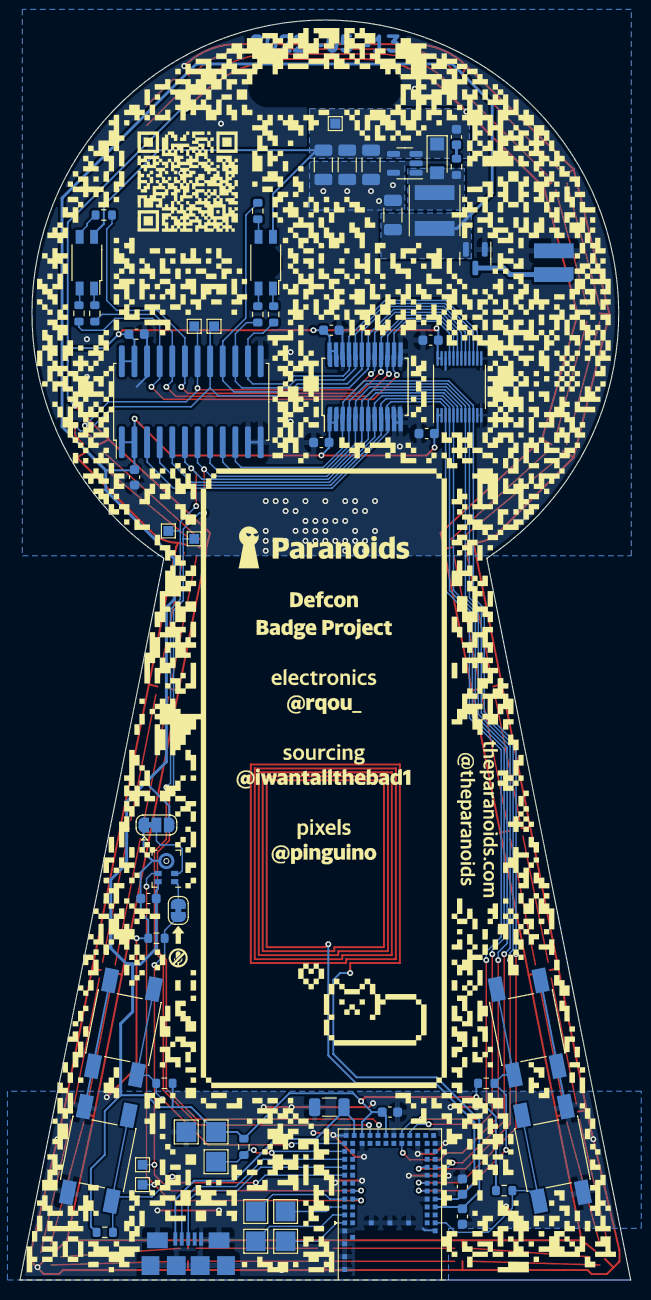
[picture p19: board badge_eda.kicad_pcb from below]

Board: 2 copper layers, 61.5 x 126.8 mm, 87 parts (63 on the bottom side), 87 nets.

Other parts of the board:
Ref**: Val**; badge-eyes
Ref**#2: Val**; background8_text_v7b

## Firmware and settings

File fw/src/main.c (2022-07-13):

// Copyright Yahoo, Licensed under the terms of the Apache-2.0 license.
// See LICENSE file in project root for terms.

#include <zephyr.h>
#include <device.h>
#include <devicetree.h>
#include <random/rand32.h>

#include "misc.h"
#include "nfc.h"
#include "nvs.h"
#include "radio.h"
#include "sound.h"
#include "usb.h"

// select from [0, n) without bias by rerolling "bad" results
static uint32_t rand_choice(uint32_t n) {
	uint64_t limit = 0x100000000ULL / n * n;

	while (1) {
		uint32_t ret = sys_rand32_get();
		if (ret < limit) {
			return ret % n;
		}
	}
}

// blinky blinky stuff
#define COLOR_GRAPE_JELLY		45, 0, 164
#define COLOR_SEA_FOAM			1, 166, 156
#define COLOR_DORY_BLUE			1, 36, 255
#define COLOR_DORY_TINT			101, 142, 246
#define COLOR_DORY_TINT_1024	406, 572, 988
#define COLOR_MALIBU			255, 0, 55
#define COLOR_MALIBU_TINT		237, 108, 154
#define COLOR_MALIBU_TINT_1024	952, 433, 618
#define COLOR_TURMERIC_YELLOW	255, 99, 0
#define COLOR_MULAH_GREEN		3, 142, 35

const uint8_t twinkle_colors_1[] = {
	COLOR_SEA_FOAM,
	COLOR_DORY_BLUE,
	COLOR_DORY_TINT,
};

const uint8_t sparkle_colors_2[] = {
	COLOR_GRAPE_JELLY,
	COLOR_DORY_TINT,
	COLOR_DORY_BLUE,
};

const uint8_t sparkle_colors_3[] = {
	COLOR_GRAPE_JELLY,
};

const uint8_t twinkle_colors_4[] = {
	COLOR_MALIBU,
	COLOR_TURMERIC_YELLOW,
	COLOR_MULAH_GREEN,
	COLOR_DORY_BLUE,
	COLOR_GRAPE_JELLY,
};

const uint16_t eye_colors_4[] = {
	COLOR_DORY_TINT_1024,
	COLOR_MALIBU_TINT_1024,
};

const uint16_t eye_colors_5[] = {
	214, 14, 1024	// Hulk pants
};

const uint8_t sparkle_colors_11[] = {
	COLOR_MALIBU,
	COLOR_TURMERIC_YELLOW,
	COLOR_MALIBU_TINT,
};

const uint8_t rainbow_cycle_colors[] = {
	255, 0, 55,
	255, 19, 38,
	255, 41, 24,
	255, 68, 11,
	255, 99, 0,
	177, 112, 6,
	111, 125, 13,
	52, 134, 23,
	3, 142, 35,
	16, 108, 71,
	20, 80, 118,
	16, 55, 179,
	1, 36, 255,
	14, 25, 229,
	26, 15, 206,
	36, 7, 184,
	45, 0, 164,
	45, 0, 164,
	92, 0, 130,
	142, 0, 101,
	196, 0, 76,
};

static void random_twinkle_loop(int num_colors, const uint8_t *colors, int delay) {
	const int max_leds = NLEDS;

	static int delay_remaining = 0;
	static int num_leds_lit = 0;

	if (delay_remaining-- >= 0) {} else {
		if (num_leds_lit == max_leds) {
			for (int i = 0; i < NLEDS; i++) {
				set_led(i, 0, 0, 0);
			}
			num_leds_lit = 0;
			delay_remaining = delay;
		} else {
			int led = rand_choice(NLEDS);
			const uint8_t *color = &colors[3 * rand_choice(num_colors)];
			set_led(led, color[0], color[1], color[2]);
			num_leds_lit++;
			delay_remaining = delay;
		}
	}
}

static void sparkle_loop(int num_colors, const uint8_t *colors, int use_eyes) {
	static int last_led_lit = -1;

	if (last_led_lit == -1) {
		// turn one on
		int led;
		if (use_eyes)
			led = rand_choice(NLEDS + 2);
		else
			led = rand_choice(NLEDS);
		const uint8_t *color = &colors[3 * rand_choice(num_colors)];

		if (led == NLEDS)
			set_left_eye(color[0] * 4, color[1] * 4, color[2] * 4);
		else if (led == NLEDS + 1)
			set_right_eye(color[0] * 4, color[1] * 4, color[2] * 4);
		else
			set_led(led, color[0], color[1], color[2]);
		last_led_lit = led;
	} else {
		// turn it off
		if (last_led_lit == NLEDS)
			set_left_eye(0, 0, 0);
		else if (last_led_lit == NLEDS + 1)
				set_right_eye(0, 0, 0);
		else
			set_led(last_led_lit, 0, 0, 0);
		last_led_lit = -1;
	}
}

static void color_wipe_loop() {
	// negative --> on the left
	// positive --> on the right
	static int num_not_lit = -NLEDS;

	if (num_not_lit <= 0) {
		for (int i = 0; i < -num_not_lit; i++) {
			set_led(i, 0, 0, 0);
		}
		for (int i = -num_not_lit; i < NLEDS; i++) {
			set_led(i, COLOR_GRAPE_JELLY);
		}

		num_not_lit++;
	}

	if (num_not_lit > 0) {
		for (int i = 0; i < NLEDS - num_not_lit; i++) {
			set_led(i, COLOR_GRAPE_JELLY);
		}
		for (int i = NLEDS - num_not_lit; i < NLEDS; i++) {
			set_led(i, 0, 0, 0);
		}

		if (num_not_lit == NLEDS)
			num_not_lit = -NLEDS;
		else
			num_not_lit++;
	}
}

static void eye_fade_loop(int num_colors, const uint16_t *colors, int reset) {
	const int num_steps = 16;

	// 0 = blank
	// 1 = up
	// 2 = down
	static int direction = 0;
	static int step = 0;
	static int color_idx = 0;

	if (reset) {
		direction = 0;
		step = 0;
		color_idx = 0;
	}

	const uint16_t *color = &colors[color_idx * 3];

	switch (direction) {
		case 0:
			set_left_eye(0, 0, 0);
			set_right_eye(0, 0, 0);
			if (++step == num_steps) {
				step = 0;
				direction = 1;
			}
			break;

		case 1:
			step++;
			set_left_eye(color[0] * step / num_steps, color[1] * step / num_steps, color[2] * step / num_steps);
			set_right_eye(color[0] * step / num_steps, color[1] * step / num_steps, color[2] * step / num_steps);
			if (step == num_steps) {
				direction = 2;
			}
			break;

		case 2:
			step--;
			set_left_eye(color[0] * step / num_steps, color[1] * step / num_steps, color[2] * step / num_steps);
			set_right_eye(color[0] * step / num_steps, color[1] * step / num_steps, color[2] * step / num_steps);
			if (step == 0) {
				direction = 0;
				color_idx = (color_idx + 1) % num_colors;
			}
			break;
	}
}

static void cylon_loop() {
	// 0 = right
	// 1 = left
	static int direction = 0;
	static int end_wait = 0;
	static int cylon_pos = 0;

	if (end_wait-- >= 0) {} else {
		for (int i = 0; i < NLEDS; i++)
			set_led(i, COLOR_GRAPE_JELLY);
		for (int i = 6; i <= 10; i++)
			set_led(i, 0, 0, 0);
		set_led(10 - cylon_pos, 163, 0, 4 /* cylon bar color */);

		if (direction == 0) {
			if (cylon_pos == 4) {
				direction = 1;
				end_wait = 1;
			} else
				cylon_pos++;
		} else {
			if (cylon_pos == 0) {
				direction = 0;
				end_wait = 1;
			} else
				cylon_pos--;
		}
	}
}

static void snow_sparkle_loop() {
	static int last_led_lit = -1;
	static int delay_remaining = 0;

	if (delay_remaining-- >= 0) {} else {
		for (int i = 0; i < NLEDS; i++)
			set_led(i, COLOR_GRAPE_JELLY);

		if (last_led_lit == -1) {
			// turn one on
			int led = rand_choice(NLEDS);
			set_led(led, 255, 255, 255);
			last_led_lit = led;
		} else {
			// turn it off (back to purple, which we already did above)
			last_led_lit = -1;
			delay_remaining = 6;
		}
	}
}

// fixme code duplication
static void fade_purples_loop() {
	const int num_steps = 16;

	// 0 = blank
	// 1 = up
	// 2 = down
	static int direction = 0;
	static int step = 0;
	static int color_idx = 0;

	switch (direction) {
		case 0:
			for (int i = 0; i < NLEDS; i++)
				set_led(i, 0, 0, 0);
			if (++step == num_steps) {
				step = 0;
				direction = 1;
			}
			break;

		case 1:
			step++;
			for (int i = 0; i < NLEDS; i++)
				// COLOR_GRAPE_JELLY
				set_led(i,
					45 * step / num_steps / (color_idx ? 4 : 1),
					0 * step / num_steps / (color_idx ? 4 : 1),
					164 * step / num_steps / (color_idx ? 4 : 1));
			if (step == num_steps) {
				direction = 2;
			}
			break;

		case 2:
			step--;
			for (int i = 0; i < NLEDS; i++)
				// COLOR_GRAPE_JELLY
				set_led(i,
					45 * step / num_steps / (color_idx ? 4 : 1),
					0 * step / num_steps / (color_idx ? 4 : 1),
					164 * step / num_steps / (color_idx ? 4 : 1));
			if (step == 0) {
				direction = 0;
				color_idx = (color_idx + 1) % 2;
			}
			break;
	}
}

static void fade_ukraine_loop() {
	const int num_steps = 16;

	// 0 = blank
	// 1 = up
	// 2 = down
	static int direction = 0;
	static int step = 0;

	switch (direction) {
		case 0:
			for (int i = 0; i < NLEDS; i++)
				set_led(i, 0, 0, 0);
			if (++step == num_steps) {
				step = 0;
				direction = 1;
			}
			break;

		case 1:
			step++;
			for (int i = 0; i < NLEDS; i++)
				if (i % 2 == 0)
					// COLOR_TURMERIC_YELLOW
					set_led(i,
						255 * step / num_steps,
						99 * step / num_steps,
						0 * step / num_steps);
				else
					// COLOR_DORY_BLUE
					set_led(i,
						1 * step / num_steps,
						36 * step / num_steps,
						255 * step / num_steps);
			if (step == num_steps) {
				direction = 2;
			}
			break;

		case 2:
			step--;
			for (int i = 0; i < NLEDS; i++)
				if (i % 2 == 0)
					// COLOR_TURMERIC_YELLOW
					set_led(i,
						255 * step / num_steps,
						99 * step / num_steps,
						0 * step / num_steps);
				else
					// COLOR_DORY_BLUE
					set_led(i,
						1 * step / num_steps,
						36 * step / num_steps,
						255 * step / num_steps);
			if (step == 0) {
				direction = 0;
			}
			break;
	}
}

static void rainbow_cycle_loop() {
	static int offset = 0;
	static int delay_remaining = 0;

	if (delay_remaining-- >= 0) {} else {
		for (int i = 0; i < NLEDS; i++) {
			const uint8_t *color = &rainbow_cycle_colors[((i + offset) % NLEDS) * 3];
			set_led(i, color[0], color[1], color[2]);
		}
		const uint8_t *color = &rainbow_cycle_colors[offset * 3];
		set_left_eye(color[0] * 4, color[1] * 4, color[2] * 4);
		set_right_eye(color[0] * 4, color[1] * 4, color[2] * 4);

		delay_remaining = 1;
		offset = (offset + 1) % NLEDS;
	}
}

static void radio_neighbor_eye_loop() {
	// fade in/out to random colors, where brightness
	// is controlled by the number of visible peers

	// if there are *any* imposters, right eye fades to red instead
	// if there are *any* easter egg badges, left eye fades to gold instead

	const int num_steps = 16;

	// 0 = blank
	// 1 = up
	// 2 = down
	static int direction = 2;
	static int step = 1;

	static int r, g, b;

	static int num_peers;
	static int num_imposters;
	static int num_badge_makers;

	int brightness_scale;
	if (num_peers == 0) {
		brightness_scale = 64;
	} else if (num_peers == 1) {
		brightness_scale = 8;
	} else if (num_peers == 2) {
		brightness_scale = 4;
	} else if (num_peers <= 5) {
		brightness_scale = 2;
	} else {
		brightness_scale = 1;
	}

	switch (direction) {
		case 0:
			set_left_eye(0, 0, 0);
			set_right_eye(0, 0, 0);
			if (++step == num_steps) {
				step = 0;
				direction = 1;
			}
			break;

		case 1:
			step++;
			set_left_eye(
				(num_badge_makers ? 1024 : r) * step / num_steps / brightness_scale,
				(num_badge_makers ? 696 : g) * step / num_steps / brightness_scale,
				(num_badge_makers ? 0 : b) * step / num_steps / brightness_scale);
			set_right_eye(
				(num_imposters ? 1024 : r) * step / num_steps / brightness_scale,
				(num_imposters ? 0 : g) * step / num_steps / brightness_scale,
				(num_imposters ? 0 : b) * step / num_steps / brightness_scale);
			if (step == num_steps) {
				direction = 2;
			}
			break;

		case 2:
			step--;
			set_left_eye(
				(num_badge_makers ? 1024 : r) * step / num_steps / brightness_scale,
				(num_badge_makers ? 696 : g) * step / num_steps / brightness_scale,
				(num_badge_makers ? 0 : b) * step / num_steps / brightness_scale);
			set_right_eye(
				(num_imposters ? 1024 : r) * step / num_steps / brightness_scale,
				(num_imposters ? 0 : g) * step / num_steps / brightness_scale,
				(num_imposters ? 0 : b) * step / num_steps / brightness_scale);
			if (step == 0) {
				direction = 0;

				// pick a new color
				int hue = rand_choice(6 * 1025);

				// awkward HSV-ish --> RGB, except S = 1 always
				int huebin = hue / 1025;
				int hue_in_bin = hue % 1025;

				switch (huebin) {
					case 0:
						r = 1024;
						g = hue_in_bin;
						b = 0;
						break;
					case 1:
						r = 1024 - hue_in_bin;
						g = 1024;
						b = 0;
						break;
					case 2:
						r = 0;
						g = 1024;
						b = hue_in_bin;
						break;
					case 3:
						r = 0;
						g = 1024 - hue_in_bin;
						b = 1024;
						break;
					case 4:
						r = hue_in_bin;
						g = 0;
						b = 1024;
						break;
					case 5:
					default:
						r = 1024;
						g = 0;
						b = 1024 - hue_in_bin;
						break;
				}

				// only update this when the leds fade out (no sudden changes)
				get_peer_infos(&num_peers, &num_imposters, &num_badge_makers);
			}
			break;
	}
}

#define NUM_PUZZLE_CODES	12
static const uint8_t PUZZLE_CODES[] = {
	2, 1, 1, 8,
	1, 5, 2, 5,
	2, 0, 2, 0,
	5, 3, 0, 9,
	9, 1, 2, 1,
	4, 2, 4, 2,
	1, 3, 3, 7,
	1, 2, 1, 5,
	1, 9, 9, 9,
	1, 2, 3, 4,
	6, 5, 4, 3,
	1, 1, 1, 1,
};
_Static_assert(sizeof(PUZZLE_CODES) == NUM_PUZZLE_CODES * 4, "Wrong NUM_PUZZLE_CODES");
_Static_assert(NUM_PUZZLE_CODES <= 32, "Too many codes");

// buttons from the *FRONT*
//   /      \
//  / 3    1 \
// / 4      2 \
// ------------

// should run at every 64 ms as long as we didn't take too long
static void game_loop(void) {
	// mode -1	==> puzzle code input
	// mode 0	==> sound/neighbor reactive mode
	// mode >=1	==> blinky blinky
	static int badge_main_mode = 0;

	static int did_init_unlocked_blinky_patterns = 0;
	static uint32_t unlocked_blinky_patterns = 0;

	if (!did_init_unlocked_blinky_patterns) {
		unlocked_blinky_patterns = nvs_get_unlocked_blinky_patterns();
		did_init_unlocked_blinky_patterns = 1;
	}

	static int last_buttons = 0;
	int this_buttons = read_all_buttons();

	int puzzle_pressed = !(last_buttons & 0b0010) && (this_buttons & 0b0010);
	int puzzle_held = this_buttons & 0b0010;

	static int puzzle_held_ticks;
	if (puzzle_pressed) {
		puzzle_held_ticks = 0;
	} else if (puzzle_held) {
		puzzle_held_ticks++;
	} else {
		puzzle_held_ticks = -1;
	}

	int mode_changed = 0;

	if (badge_main_mode > -1) {
		// button 2 ==> "right"
		// button 3 ==> "puzzle"
		// button 4 ==> "left"

		int left_pressed = !(last_buttons & 0b0001) && (this_buttons & 0b0001);
		int right_pressed = !(last_buttons & 0b0100) && (this_buttons & 0b0100);

		if (unlocked_blinky_patterns) {
			if (left_pressed && !right_pressed) {
				if (badge_main_mode) {
					// using a blinky right now
					// go down and find the next unlocked pattern
					// if there isn't one, go to mode 0
					int i;
					for (i = badge_main_mode - 1; i > 0; i--) {
						if (unlocked_blinky_patterns & (1 << (i - 1)))
							break;
					}
					badge_main_mode = i;
				} else {
					// sound-reactive mode right now
					// find highest set
					badge_main_mode = 32 - __builtin_clz(unlocked_blinky_patterns);

				}

				for (int i = 0; i < NLEDS; i++)
					set_led(i, 0, 0, 0);
				mode_changed = 1;
				printk("badge mode is now %d\n", badge_main_mode);
			}

			if (!left_pressed && right_pressed) {
				// go up and find the next unlocked pattern
				// if there isn't one, go to mode 0
				int i;
				for (i = badge_main_mode + 1; i <= NUM_PUZZLE_CODES; i++) {
					if (unlocked_blinky_patterns & (1 << (i - 1)))
						break;
				}

				if (i == NUM_PUZZLE_CODES + 1)
					badge_main_mode = 0;
				else
					badge_main_mode = i;

				for (int i = 0; i < NLEDS; i++)
					set_led(i, 0, 0, 0);
				mode_changed = 1;
				printk("badge mode is now %d\n", badge_main_mode);
			}
		}

		if (puzzle_held_ticks >= 78) {
			// held for 5 seconds
			badge_main_mode = -1;
			puzzle_held_ticks = 0;
			printk("badge mode is now %d\n", badge_main_mode);
		}
	}

	if (badge_main_mode == 0) {
		// this is the default sound/neighbor mode
		radio_neighbor_eye_loop();
		// XXX the *sound* processing is in sound.c, only the radio neighbor logic is here
	} else if (badge_main_mode == -1) {
		// this is the "puzzle input" mode
		set_left_eye(0, EYE_MAX_VAL - 1, 0);
		set_right_eye(0, EYE_MAX_VAL - 1, 0);

		if (puzzle_held_ticks >= 78) {
			// held for 5 seconds, cancel
			badge_main_mode = 0;
			puzzle_held_ticks = 0;
			printk("badge mode is now %d\n", badge_main_mode);
		}

		static int code0 = 0;
		static int code1 = 0;
		static int code2 = 0;
		static int code3 = 0;

		int code0_pressed = !(last_buttons & 0b0010) && (this_buttons & 0b0010);
		int code1_pressed = !(last_buttons & 0b0001) && (this_buttons & 0b0001);
		int code2_pressed = !(last_buttons & 0b1000) && (this_buttons & 0b1000);
		int code3_pressed = !(last_buttons & 0b0100) && (this_buttons & 0b0100);

		if (code0_pressed)
			code0 = (code0 + 1) % 10;
		if (code1_pressed)
			code1 = (code1 + 1) % 10;
		if (code2_pressed)
			code2 = (code2 + 1) % 10;
		if (code3_pressed)
			code3 = (code3 + 1) % 10;

		// printk("code is now %d%d%d%d\n", code0, code1, code2, code3);

		set_led(0, 0, 0, 0);

		set_led(1,
			code2 == 7 ? 255 : 0,
			code2 == 8 ? 255 : 0,
			code2 == 9 ? 255 : 0);
		set_led(2,
			code2 == 4 ? 255 : 0,
			code2 == 5 ? 255 : 0,
			code2 == 6 ? 255 : 0);
		set_led(3,
			code2 == 1 ? 255 : 0,
			code2 == 2 ? 255 : 0,
			code2 == 3 ? 255 : 0);

		set_led(4,
			code3 == 7 ? 255 : 0,
			code3 == 8 ? 255 : 0,
			code3 == 9 ? 255 : 0);
		set_led(5,
			code3 == 4 ? 255 : 0,
			code3 == 5 ? 255 : 0,
			code3 == 6 ? 255 : 0);
		set_led(6,
			code3 == 1 ? 255 : 0,
			code3 == 2 ? 255 : 0,
			code3 == 3 ? 255 : 0);

		set_led(7, 0, 0, 0);
		set_led(8, 0, 0, 0);
		set_led(9, 0, 0, 0);

		set_led(10,
			code1 == 1 ? 255 : 0,
			code1 == 2 ? 255 : 0,
			code1 == 3 ? 255 : 0);
		set_led(11,
			code1 == 4 ? 255 : 0,
			code1 == 5 ? 255 : 0,
			code1 == 6 ? 255 : 0);
		set_led(12,
			code1 == 7 ? 255 : 0,
			code1 == 8 ? 255 : 0,
			code1 == 9 ? 255 : 0);

		set_led(13,
			code0 == 1 ? 255 : 0,
			code0 == 2 ? 255 : 0,
			code0 == 3 ? 255 : 0);
		set_led(14,
			code0 == 4 ? 255 : 0,
			code0 == 5 ? 255 : 0,
			code0 == 6 ? 255 : 0);
		set_led(15,
			code0 == 7 ? 255 : 0,
			code0 == 8 ? 255 : 0,
			code0 == 9 ? 255 : 0);

		set_led(16, 0, 0, 0);
		set_led(17, 0, 0, 0);
		set_led(18, 0, 0, 0);
		set_led(19, 0, 0, 0);
		set_led(20, 0, 0, 0);

		int matched_code = -1;
		for (int i = 0; i < NUM_PUZZLE_CODES; i++) {
			if (code0 == PUZZLE_CODES[i*4+0] &&
				code1 == PUZZLE_CODES[i*4+1] &&
				code2 == PUZZLE_CODES[i*4+2] &&
				code3 == PUZZLE_CODES[i*4+3]) {
				printk("Matched code %d\n", i);
				matched_code = i;
				break;
			}
		}

		if (matched_code >= 0) {
			code0 = code1 = code2 = code3 = 0;

			unlocked_blinky_patterns |= (1 << matched_code);
			badge_main_mode = matched_code + 1;
			nvs_set_unlocked_blinky_patterns(unlocked_blinky_patterns);
			badge_nfc_set_msg_puzzle(unlocked_blinky_patterns);
			printk("unlocked patterns are now %08X\n", unlocked_blinky_patterns);
			for (int i = 0; i < NLEDS; i++)
				set_led(i, 0, 0, 0);
			printk("badge mode is now %d\n", badge_main_mode);
		}
	} else {
		// blinky blinky patterns
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
void main(void)
{
	int ret;

	if ((ret = nvs_setup())) {
		printk("NVS setup failed: %d\n", ret);
		return;
	}

	if ((ret = badge_usb_setup())) {
		printk("USB setup failed: %d\n", ret);
		return;
	}

	if ((ret = setup_eyes())) {
		printk("Eyes setup failed: %d\n", ret);
		return;
	}

	if ((ret = setup_leds())) {
		printk("LED setup failed: %d\n", ret);
		return;
	}

	if ((ret = setup_buttons())) {
		printk("Button setup failed: %d\n", ret);
		return;
	}

	if ((ret = badge_nfc_setup())) {
		printk("NFC setup failed: %d\n", ret);
		return;
	}

	if ((ret = badge_bt_setup())) {
		printk("Bluetooth setup failed: %d\n", ret);
		return;
	}

	if ((ret = setup_sound())) {
		printk("Sound setup failed: %d\n", ret);
		return;
	}

	enum factory_mode factory_mode_ = nvs_get_factory();

	if (factory_mode_ >= factory_before_mic_ok) {
		if ((ret = start_sound())) {
			printk("Sound start failed: %d\n", ret);
			return;
		}
	}

	int factory_chaser_idx = 0;

	while (1) {
		switch (factory_mode_) {
			case factory_before_sw1:
			default:
				set_left_eye(EYE_MAX_VAL - 1, 0, 0);
				set_right_eye(EYE_MAX_VAL - 1, 0, 0);

				for (int i = 0; i < NLEDS; i++) {
					if (i == factory_chaser_idx)
						set_led(i, 255, 0, 0);
					else if (i == (factory_chaser_idx + 1) % NLEDS)
						set_led(i, 0, 255, 0);
					else if (i == (factory_chaser_idx + 2) % NLEDS)
						set_led(i, 0, 0, 255);
					else
						set_led(i, 0, 0, 0);
				}
				update_leds();
				factory_chaser_idx = (factory_chaser_idx + 1) % NLEDS;

				if (read_all_buttons() & 0b1000) {
					factory_mode_ = factory_before_sw2;
					nvs_set_factory(factory_mode_);

					printk("Factory: SW1 pressed\n");
				}

				k_msleep(300);
				break;

			case factory_before_sw2:
				set_left_eye(0, EYE_MAX_VAL - 1, 0);
				set_right_eye(0, EYE_MAX_VAL - 1, 0);

				set_led(0, 255, 255, 255);
				for (int i = 1; i < NLEDS; i++) {
					set_led(i, 0, 0, 0);
				}
				update_leds();

				if (read_all_buttons() & 0b0100) {
					factory_mode_ = factory_before_sw3;
					nvs_set_factory(factory_mode_);

					printk("Factory: SW2 pressed\n");
				}
				break;

			case factory_before_sw3:
				set_left_eye(0, 0, EYE_MAX_VAL - 1);
				set_right_eye(0, 0, EYE_MAX_VAL - 1);

				set_led(0, 255, 255, 255);
				set_led(1, 255, 255, 255);
				for (int i = 2; i < NLEDS; i++) {
					set_led(i, 0, 0, 0);
				}
				update_leds();

				if (read_all_buttons() & 0b0010) {
					factory_mode_ = factory_before_sw4;
					nvs_set_factory(factory_mode_);
				
					printk("Factory: SW3 pressed\n");
				}
				break;

			case factory_before_sw4:
				set_left_eye(EYE_MAX_VAL - 1, EYE_MAX_VAL - 1, EYE_MAX_VAL - 1);
				set_right_eye(EYE_MAX_VAL - 1, EYE_MAX_VAL - 1, EYE_MAX_VAL - 1);

				set_led(0, 255, 255, 255);
				set_led(1, 255, 255, 255);
				set_led(2, 255, 255, 255);
				for (int i = 3; i < NLEDS; i++) {
					set_led(i, 0, 0, 0);
				}
				update_leds();

				if (read_all_buttons() & 0b0001) {
					factory_mode_ = factory_before_mic_ok;
					nvs_set_factory(factory_mode_);
				
					printk("Factory: SW4 pressed\n");

					if ((ret = start_sound())) {
						printk("Sound start failed: %d\n", ret);
						return;
					}
				}
				break;

			case factory_before_mic_ok:
				set_left_eye(EYE_MAX_VAL - 1, EYE_MAX_VAL - 1, EYE_MAX_VAL - 1);
				set_right_eye(EYE_MAX_VAL - 1, EYE_MAX_VAL - 1, EYE_MAX_VAL - 1);

				for (int i = 0; i < NLEDS; i++) {
					set_led(i, 255, 255, 255);
				}
				update_leds();

				int sound_passed = process_sound_factory();

				if (sound_passed) {
					factory_mode_ = factory_completed;
					nvs_set_factory(factory_mode_);

					printk("Factory: Mic check passed\n");
				}
				break;

			case factory_completed:
				game_loop();
				break;
		}
	}
}

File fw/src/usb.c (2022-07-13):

// Copyright Yahoo, Licensed under the terms of the Apache-2.0 license.
// See LICENSE file in project root for terms.

#include <ctype.h>
#include <stdlib.h>
#include <zephyr.h>
#include <sys/ring_buffer.h>
#include <drivers/uart.h>
#include <usb/usb_device.h>

#include "nfc.h"
#include "nvs.h"
#include "sound.h"
#include "usb.h"

K_PIPE_DEFINE(usb_rxpipe, 512, 1);
RING_BUF_DECLARE(usb_txring, 4096);

const struct device *const cdcacm_dev = DEVICE_DT_GET_ONE(zephyr_cdc_acm_uart);

static void interrupt_handler(const struct device *dev, void *user_data)
{
	ARG_UNUSED(user_data);

	while (uart_irq_update(dev) && uart_irq_is_pending(dev)) {
		if (uart_irq_rx_ready(dev)) {
			int recv_len, rb_len;
			uint8_t buffer[64];
			size_t len = MIN(k_pipe_write_avail(&usb_rxpipe),
					 sizeof(buffer));

			recv_len = uart_fifo_read(dev, buffer, len);
			if (recv_len < 0) {
				printk("Failed to read CDCACM FIFO\r\n");
				recv_len = 0;
			};

			k_pipe_put(&usb_rxpipe, buffer, recv_len, &rb_len, 0, K_NO_WAIT);
			if (rb_len < recv_len) {
				printk("Drop %u rx bytes\r\n", recv_len - rb_len);
			}
		}

		if (uart_irq_tx_ready(dev)) {
			uint8_t buffer[64];
			int rb_len, send_len;

			rb_len = ring_buf_get(&usb_txring, buffer, sizeof(buffer));
			if (!rb_len) {
				uart_irq_tx_disable(dev);
				continue;
			}

			send_len = uart_fifo_fill(dev, buffer, rb_len);
			if (send_len < rb_len) {
				printk("Drop %d tx bytes\r\n", rb_len - send_len);
			}
		}
	}
}

static int echo_is_on;

static uint8_t rx_getchar() {
	uint8_t c[2];
	size_t sz;
	k_pipe_get(&usb_rxpipe, &c, 1, &sz, 1, K_FOREVER);
	if (echo_is_on) {
		if (c[0] == '\r' || c[0] == '\n') {
			// echo CRLF for either CR or LF
			c[0] = '\r';
			c[1] = '\n';
			badge_usb_write(c, 2);
		} else {
			badge_usb_write(c, 1);
		}
	}
	return c[0];
}

enum LineEditState {
	LineNone,
	LineSawCR,
	LineSawEsc,
	LineSawEscLBracket,
};

static uint32_t rx_getline(uint8_t *buf, uint32_t bufsz) {
	uint32_t pos = 0;
	uint32_t len = 0;
	enum LineEditState state = LineNone;

	while (1) {
		uint8_t c[3];
		size_t _;
		k_pipe_get(&usb_rxpipe, &c, 1, &_, 1, K_FOREVER);

		switch (state) {
			case LineSawCR:
				if (c[0] == '\n') {
					// This is a stray LF from the last line ending we saw, so deliberately ignore it
					// State goes back to normal though
					state = LineNone;
					break;
				}
				// deliberate fall through
			case LineNone:
				// Not processing any kind of escape sequence

				if (c[0] == '\r' || c[0] == '\n') {
					// Got a newline, we are done!

					if (echo_is_on) {
						// Gotta echo the newline though
						c[0] = '\r';
						c[1] = '\n';
						badge_usb_write(c, 2);
					}

					if (c[0] == '\r')
						state = LineSawCR;

					return len;
				}

				if (c[0] == '\x08' || c[0] == '\x7f') {
					// A backspace or a delete
					if (len == 0 || pos == 0)
						break;

					if (echo_is_on) {
	                	// Echo a backspace explicitly (screen doesn't like 0x7f)
	                	c[0] = '\x08';
	                	badge_usb_write(c, 1);
	                }

	                if (len != pos) {
	                    // Deleting a character from the middle, so we need to move everything left
	                    memmove(&buf[pos - 1], &buf[pos], len - pos);

	                    // Need to reprint everything too
	                    if (echo_is_on) {
	                    	badge_usb_write(&buf[pos - 1], len - pos);
		                }
	                }

	                if (echo_is_on) {
		                // Need this to actually wipe the (deleted/last) character away
		                c[0] = ' ';
		                c[1] = '\x08';
		                badge_usb_write(c, 2);

		                // Need to adjust the cursor back
		                c[0] = '\x08';
		                for (int _ = 0; _ < len - pos; _++) {
		                	badge_usb_write(c, 1);
		                }
		            }

	                pos -= 1;
	                len -= 1;
	                break;
				}

				if (c[0] == '\x1b') {
					// An escape
					state = LineSawEsc;
					break;
				}

	            // Just inserting a normal character

	            // If length is full, do nothing
	            if (len == bufsz) {
	                break;
	            }

	            if (len != pos) {
	                // Inserting something in the middle, so we need to move everything right
	                memmove(&buf[pos + 1], &buf[pos], len - pos);
	            }

	            buf[pos] = c[0];

	            if (echo_is_on) {
		            // Echo the character
		            badge_usb_write(c, 1);

		            // If a character was inserted, we have to print everything else too
		            if (len != pos) {
		            	badge_usb_write(&buf[pos + 1], len - pos);

		                // Now backspace to the same position
		                c[0] = '\x08';
		                for (int _ = 0; _ < len - pos; _++) {
		                	badge_usb_write(c, 1);
		                }
		            }
		        }

	            pos++;
	            len++;
	            break;
	        case LineSawEsc:
	            // Got ESC-[
	            if (c[0] == '[') {
	                state = LineSawEscLBracket;
	            } else {
	            	state = LineNone;
	            }
	            break;
	        case LineSawEscLBracket:
	            // Left arrow
	            if (c[0] == 'D') {
	                if (pos != 0) {
	                    pos--;

	                    if (echo_is_on) {
		                    // Echo the entire sequence
		                    c[0] = '\x1b';
		                    c[1] = '[';
		                    c[2] = 'D';
		                    badge_usb_write(c, 3);
		                }
	                }
	            }
	            // Right arrow
	            else if (c[0] == 'C') {
	                if (pos != len) {
	                    pos++;

	                    if (echo_is_on) {
		                    // Echo the entire sequence
		                    c[0] = '\x1b';
		                    c[1] = '[';
		                    c[2] = 'C';
		                    badge_usb_write(c, 3);
		                }
	                }
	            } else {
	                // Got ESC[-x which we don't understand. Just ignore it
	            }
	            state = LineNone;
	            break;
		}
	}
}

static void usb_putstr(const char *str) {
	badge_usb_write(str, strlen(str));
}
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
